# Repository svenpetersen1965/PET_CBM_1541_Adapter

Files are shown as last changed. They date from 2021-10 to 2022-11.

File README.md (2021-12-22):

# PET_CBM_1541_Adapter
This is an adapter for connecting the 1541 (or other IEC floppy disk drives) to the Userport of a CBM8032 etc. It is the reconstruction of a hardware, that fits to an old EPROM, that was found in a CBM8032. Most likely, it works with other BASIC 4.0 CBM/PET computers.

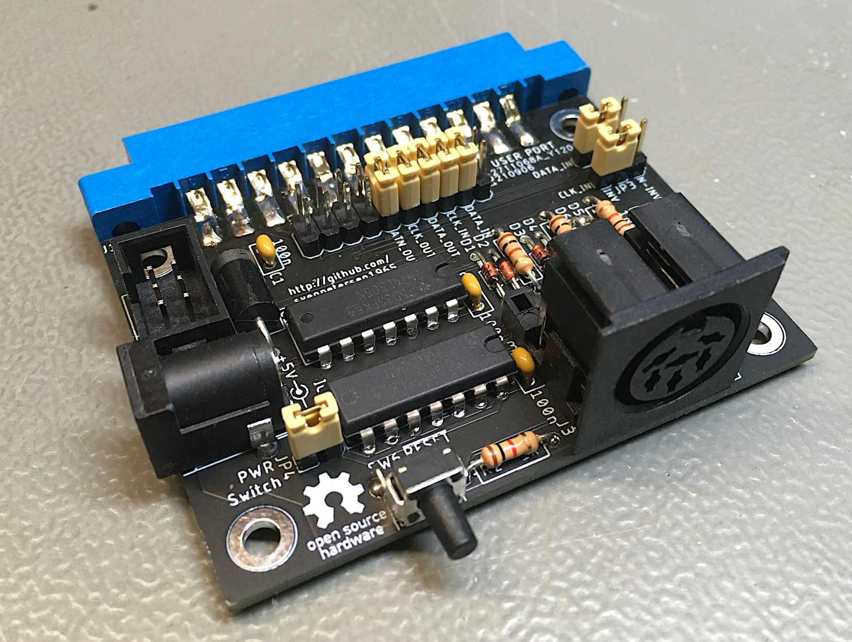
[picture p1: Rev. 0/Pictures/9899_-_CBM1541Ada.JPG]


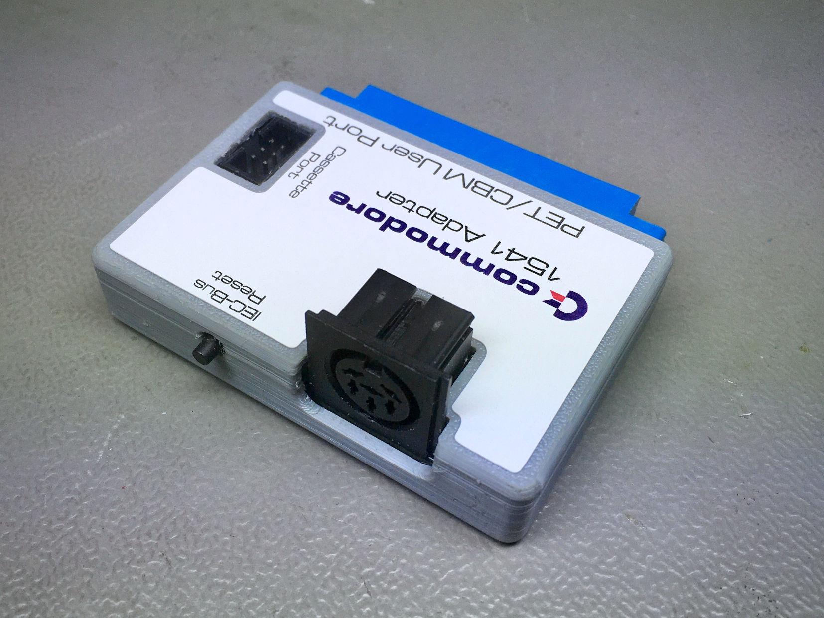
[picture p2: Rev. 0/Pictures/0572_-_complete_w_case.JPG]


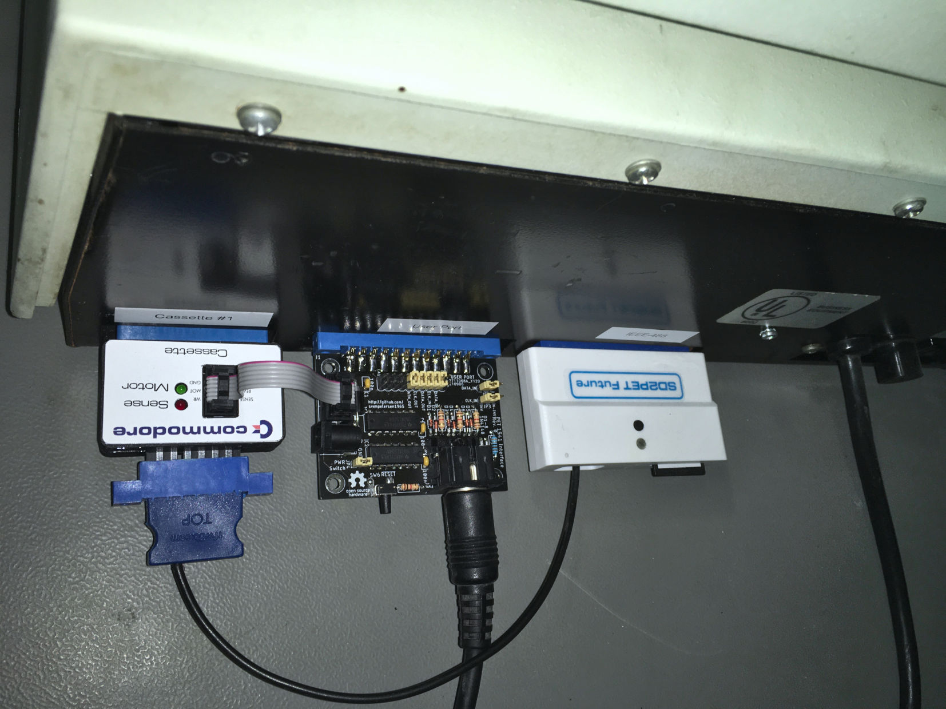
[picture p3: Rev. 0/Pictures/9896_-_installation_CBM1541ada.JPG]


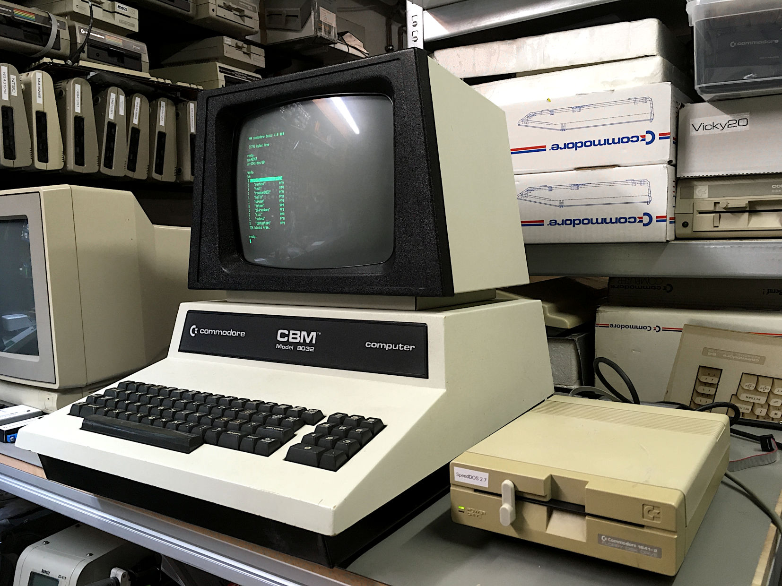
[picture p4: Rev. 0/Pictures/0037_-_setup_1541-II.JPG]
Setup


For communication with the disk drive, a special instruction set is required.

•	each instruction starts with '!'<br> 
•	there are a couple of floppy disk related instructions, that have an alternative representation in the EPROM<br>
•	a !q will deactivate/quite the software<br>
•	a !@ will display the status of the 1541<br>
•	a !@"command" will send a command to the 1541<br>
•	No device number (,8) is required for any of the instructions<br>
•	The instructions are mostly standard BASIC4 instructions and can be short-cut as usually

!load"progname": 	       loads a program from 1541 <br>
!save"progname": 	       saves a program to 1541 <br>
!verify"progname":	       verifies a program <br>
!catalog: 	               displays the driectory of the floppy disk in the 1541 <br>
!open#SA,"file name": 	   it requires a # and after that it is a secondary address* <br>
!print#,"text": 	         prints a texts, also a secondary address after #* <br>
!get#: 	   * <br>
!close#SA: 	               closes a file, also a secondary address after #* <br>
!input#SA: *<br>  
!cmd: *<br>

The items marked with * require some further investigation. See the test documentation.

The software resides in a 2532 EPROM in UD11 and is started with SYS40960.

Find more in the project documentation and <a href="http://tech.guitarsite.de/cbm_1541_ada.html">my website</a> 

Mike Naberezny  did some further inverstigation of the EPROM binary/disassembly and has found out some interesting details. Check out his <a href="https://github.com/mnaberez/vc1541dos">github repository</a>.

# Fixes
The CB2 was improperly labled as CA2. This is fixed in the Gerbers v0a. This had no effect on the function of the circuit.

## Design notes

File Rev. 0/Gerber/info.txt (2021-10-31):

      
       Board: PET_1541_Ada
       Rev.:  0
  
       Files:
       ======
  
       All Gerber files are generated in extended gerber format (RS274X)
       *.TOP        : Film top copper
       *.BOT        :  -"- bottom copper
       *.STC        :  -"- top soldermask 
       *.STS        :  -"- bottom soldermask
       *.PLC        :  -"- silk screen top
       *.DK         : Drills plated Through (Excellon)
       *.NDK        : Drills not plated Through (Excellon)
       *.OUT        : Board outline

       Board Size:
       ===========
       Length     :   68.0 mm
       Width      :   49.0 mm
       Thickness  :   1.6 mm
       Material   :   FR 4
       Copper     :   35 um
       Surface    :   HASL
       
       Remarks:
       ========
       Width >= 8mil
       Distance >= 6mil
       Drill >= 0.35mm

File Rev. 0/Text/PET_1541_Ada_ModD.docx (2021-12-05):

Commodore PET/CBM 1541 Adapter Rev. 0

Module Description

# Introduction

This is a reconstruction of an unknown hardware, which fits to the software from an EPROM, that was discovered in a CBM8032. It is an adapter for a 1541 Floppy Disk Drive, which connects to the User Port of CBM computers like the 8032.

The IEC port only allows to connect a floppy disk drive with device number 8 (which does not interfere with a device number 8 on the IEEE-488 bus!). The instructions for accessing the 1541 are not standard instructions (but very similar). Thus, the 1541 cannot replace an IEEE-488 floppy disk drive, when it comes to accessing files (SEQ or SER) or saving a machine language/assembler program from a monitor like the TIM.

It is good for saving and loading programs on/from the 1541, showing the directory (non- destructive) or displaying the disk status.

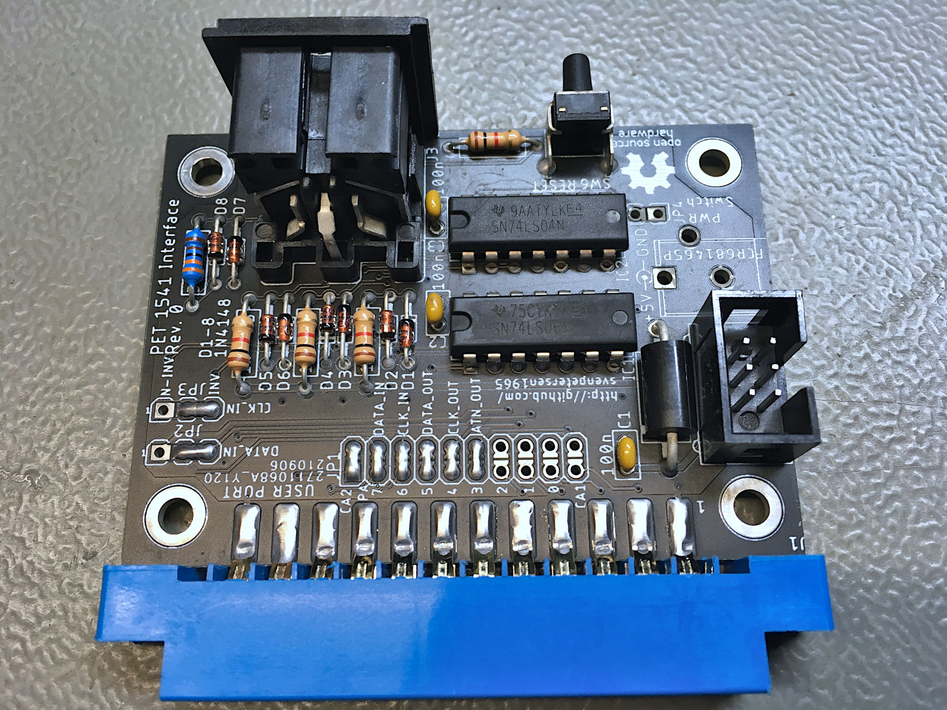
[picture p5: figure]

Figure 1: Standard assembly of the PET/CBM 1541 Adapter with the minimal required components

# Requirements

Since the User Port of the CBM and PETs does not provide a 5V supply voltage, it can be tapped at a cassette port dongle. It is recommended to use the C64 diagnostic harness cassette dongle for this purpose (it can be found here: https://github.com/svenpetersen1965/C64-Diagnostic-Rev.-586220-Harness). Further, the 6 pin ribbon cable of the previously mentioned project is required.

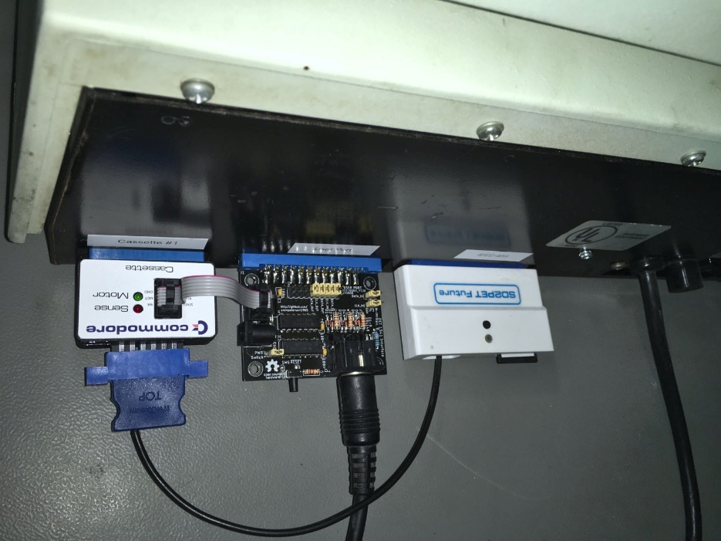
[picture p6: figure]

Figure 2: PET/CBM 1541 adapter with cassette port dongle (and an SD2PET) with a CBM8032

Also, the VC-1541-DOS/80 EPROM is required to be installed in the EPROM socket UD11.

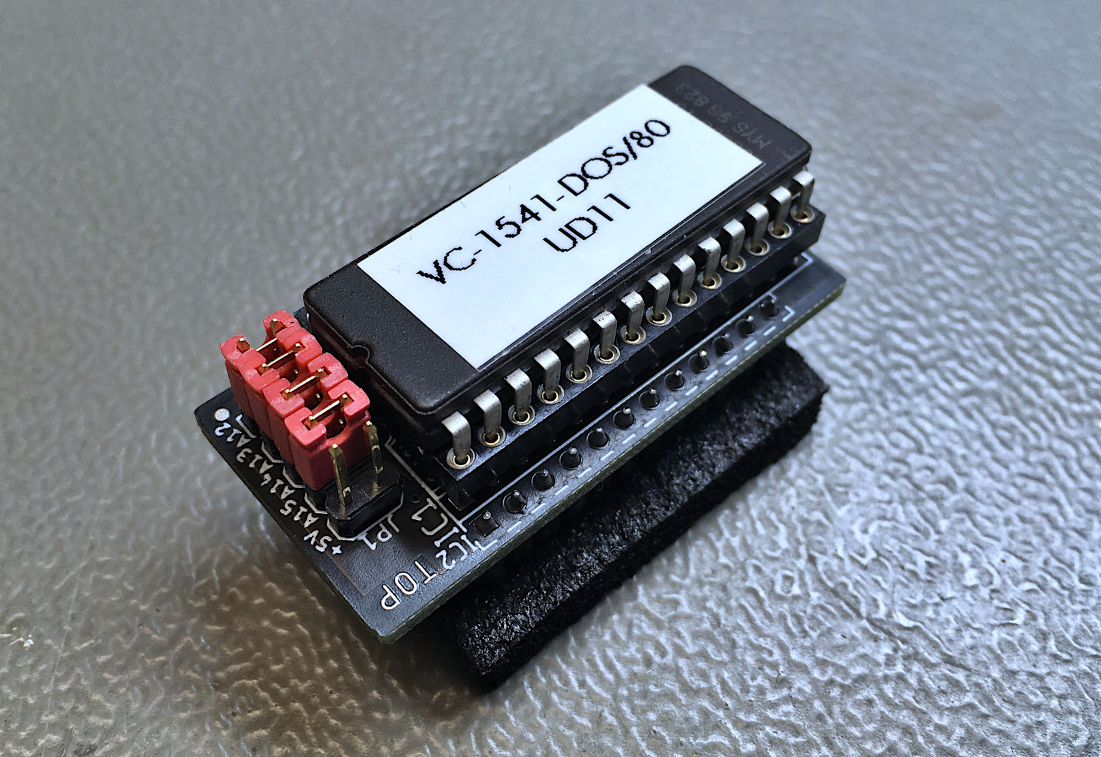
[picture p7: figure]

Figure 3: The Driver Software EPROM.

Originally, the driver software was burned in a TMS2532 4kB EPROM, which directly fits in the socket UD11 on the CBM mainboard. Since those are hard to get and not programmable with many EPROMmers, like the TL866, very likely, an adapter is required like shown in Figure 3.

# Instruction Set

The instruction set was derived from analyzing the binary of the driver software. The software is started with

SYS40960

The software will answer

vc-1541-dos/80

ready.

The instructions follow these rules:

- each instruction starts with '!'
- there are a couple of floppy disk related instructions, that have an alternative representation in the EPROM
- a !q will deactivate/quite the software
- a !@ will display the status of the 1541
- a !@"command" will send a command to the 1541
- No device number (,8) is required for any of the instructions
- The instructions are mostly standard BASIC4 instructions and can be short-cut as usually

Instruction | Format | Note
load | !load"progname" | loads a program from 1541
save | !save"progname" | saves a program to 1541
verify | !verify"progname" | verifies a program
catalog | !catalog | displays the driectory of the floppy disk in the 1541
open | !open#SA,"file name" | it requires a # and after that it is a secondary address*
print# | !print#,"text" | prints a texts, also a secondary address after #*
get# | * | *
close | !close#SA | closes a file, also a secondary address after #*
input# | !input#SA...* | *
cmd | !cmd...* | *

The items marked with * require some further investigation. See the test documentation.

The commands, which are usually sent to the 1541 via secondary address 15, can be sent with the !@ command.

Command | Function
!@"s:file name" | Scratch the file <file name>
!@"n0:disk name,xx,yy" | Format disk
!@"i" | Initialize disk
!@"v" | Validate disk
!@ | Displays the disk status
[…] | […]

# Dimensions

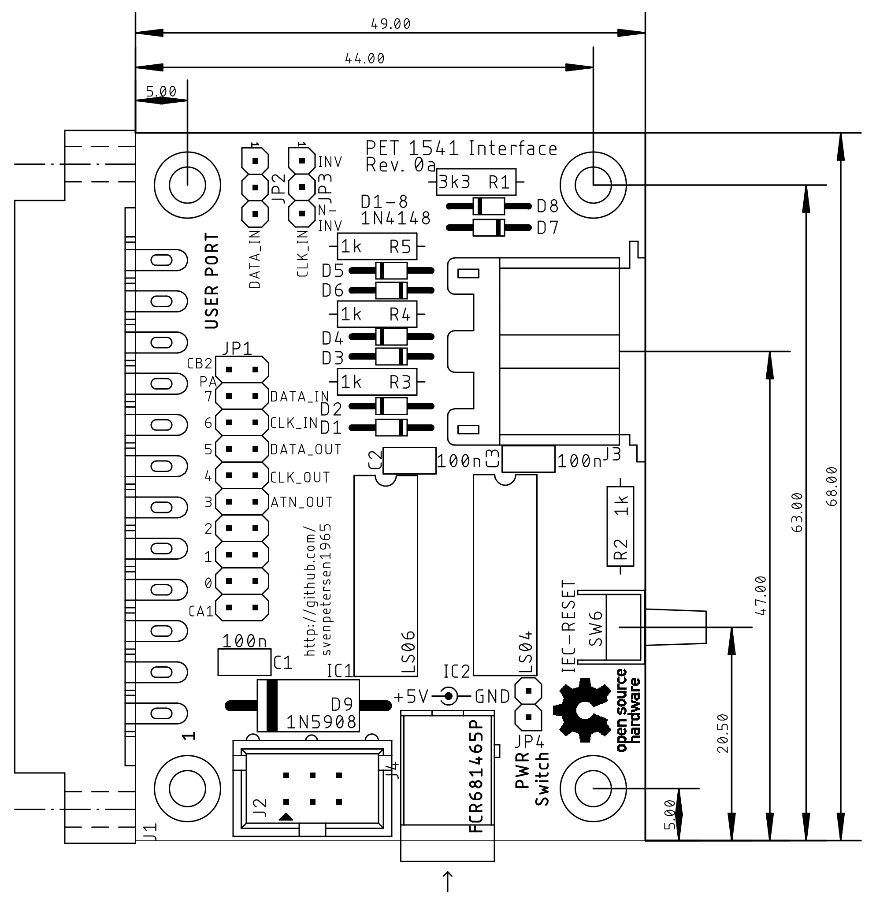
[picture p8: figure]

Figure 4: PCB Dimensions

# RESET Switch – SW6

The RESET Switch is a bus reset for the 1541 only. It does not reset the computer. It is a standard 90° TACT-switch.

# Connectors

## Cassette Port Dongle

J2 – 2x3 pin header for a ribbon cable connected to the cassette port PCB (project number 114).

Pin | Signal | Pin | Signal
1 | GND | 2 | +5V
3 | n.c. | 4 | n.c.
5 | n.c. | 6 | n.c.

n.c.: not connected

## +5VDC Power

J4 - 5,5mm/2,5mm barrel connector

Pin | Signal
Center | +5VDC
Shaft | GND

This connector is optional and not required, if it is intended to power the interface from the cassette port dongle. To make use of it, JP4 has to be closed, which can be achieved with a jumper, a solder bridge or a (power) switch.

## IEC-Bus (1541)

J3 – Lumberg 010599 06, 6p DIN receptacles

Pin | Signal
1 | n.c.
2 | GND
3 | ATN
4 | CLK
5 | DATA
6 | /RESET

/RESET is a drive reset, not a PET reset.

# Jumpers

The jumpers show the experimental character of the prototype design. They can be fix settings and don’t need to be changed at any time. Thus, it is recommended to close them with a solder bridge as shown in Figure 1.

## JP1 - User Port Connections

Signal | Pin | Pin | Signal | Setting
CB2 | 1 | 2 | n.c. | Don’t care
PA7 | 3 | 4 | DATA_IN* | close
PA6 | 5 | 6 | CLK_IN* | close
PA5 | 7 | 8 | DATA_OUT* | close
PA4 | 9 | 10 | CLK_OUT* | close
PA3 | 11 | 12 | ATN_OUT* | close
PA2 | 13 | 14 | n.c. | Don’t care
PA1 | 15 | 16 | n.c. | Don’t care
PA0 | 17 | 18 | n.c. | Don’t care
CA1 | 19 | 20 | n.c. | Don’t care

## JP2, JP3 – Input Inversion

Jumper | Pin 1 | Pin 2 | Pin 3 | Setting
JP2 | /DATA_IN | DATA_IN* | DATA_IN | Non-inverting (2-3)
JP3 | /CLK_IN | CLK_IN* | CLK_IN | Non-inverting (2-3)

## JP4 – Power Switch

This Jumper can be used to connect a power switch or it can be closed. The +5V from the barrel connector are connected to the interface’s supply voltage with the jumper. The +5V from the cassette port dongle are always connected and do not require to be switched. JP4 is only required in conjunction with J3 (See chapter +5VDC Power).

# Revision History

## Rev. 0

- Fully functional prototype

PET_1541_Ada_ModD.docx 05.12.2021 00:55 Drafted by Sven Petersen Page 2 of 2 Doc.-No.: 186-6-01-00

PET_1541_Ada_ModD.docx 05.12.2021 00:55 Drafted by Sven Petersen Page 1 of 1 Doc.-No.: 000-6-00-00

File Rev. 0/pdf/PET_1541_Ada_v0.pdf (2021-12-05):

# Project Documentation

## Commodore PET/CBM 1541 Adapter

## Project number: 186

## Revision: 0

## Date: 23.10.2021

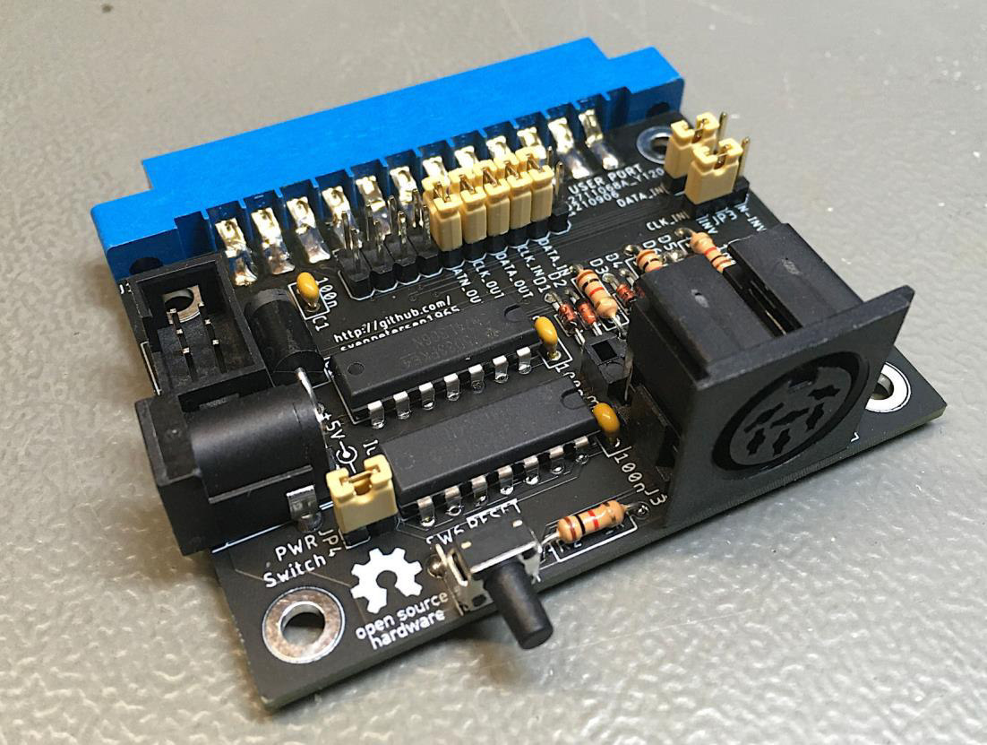
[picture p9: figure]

PET_1541_Ada_ModD.docx | | 05.12.2021 00:55
Drafted by Sven Petersen | Page 1 of 6 | Doc.-No.: 186-6-01-00

## Commodore PET/CBM 1541 Adapter Rev. 0

## Module Description

Table of Content

## Introduction

This is a reconstruction of an unknown hardware, which fits to the software from an EPROM, that was discovered in a CBM8032. It is an adapter for a 1541 Floppy Disk Drive, which connects to the User Port of CBM computers like the 8032.

The IEC port only allows to connect a floppy disk drive with device number 8 (which does not interfere with a device number 8 on the IEEE-488 bus!). The instructions for accessing the 1541 are not standard instructions (but very similar). Thus, the 1541 cannot replace an IEEE-488 floppy disk drive, when it comes to accessing files (SEQ or SER) or saving a machine language/assembler program from a monitor like the TIM.

It is good for saving and loading programs on/from the 1541, showing the directory (non-destructive) or displaying the disk status.

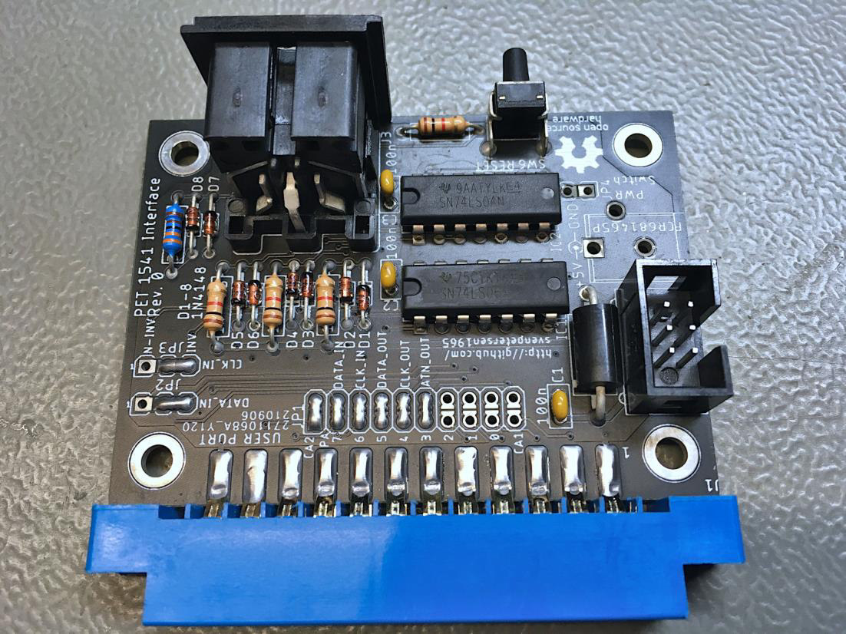
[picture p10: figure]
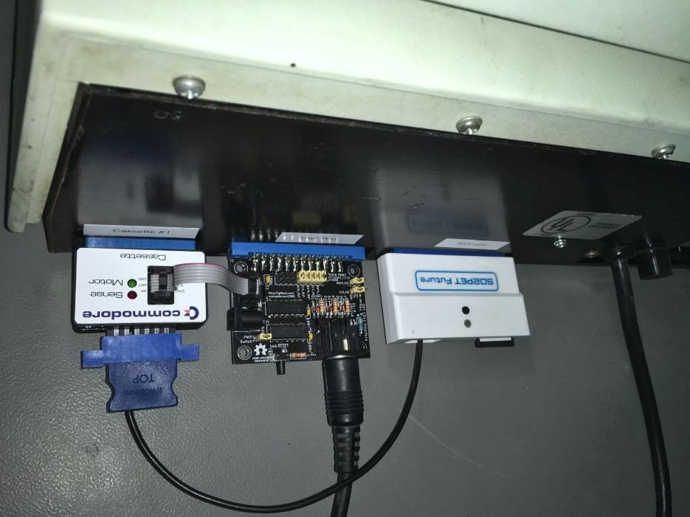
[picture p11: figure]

PET_1541_Ada_ModD.docx | | 05.12.2021 00:55
Drafted by Sven Petersen | Page 2 of 6 | Doc.-No.: 186-6-01-00

Figure 1: Standard assembly of the PET/CBM 1541 Adapter with the minimal required components

## Requirements

Since the User Port of the CBM and PETs does not provide a 5V supply voltage, it can be tapped at a cassette port dongle. It is recommended to use the C64 diagnostic harness cassette dongle for this purpose (it can be found here: https://github.com/svenpetersen1965/C64-Diagnostic-Rev.-586220-Harness). (https://github.com/svenpetersen1965/C64-Diagnostic-Rev.-586220-Harness) Further, the 6 pin ribbon cable of the previously mentioned project is required.

Figure 2: PET/CBM 1541 adapter with cassette port dongle (and an SD2PET) with a CBM8032

Also, the VC-1541-DOS/80 EPROM is required to be installed in the EPROM socket UD11.

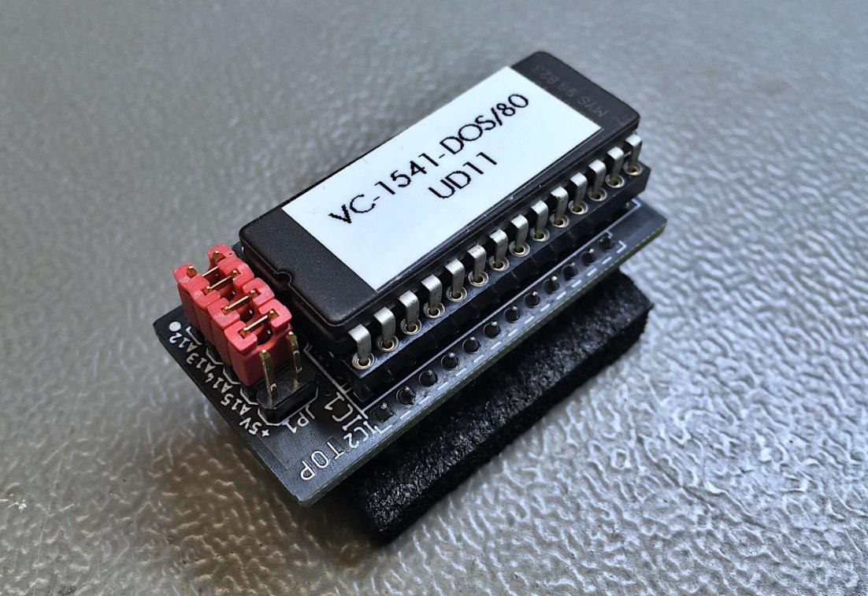
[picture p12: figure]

PET_1541_Ada_ModD.docx | | 05.12.2021 00:55
Drafted by Sven Petersen | Page 3 of 6 | Doc.-No.: 186-6-01-00

Figure 3: The Driver Software EPROM.

Originally, the driver software was burned in a TMS2532 4kB EPROM, which directly fits in the socket UD11 on the CBM mainboard. Since those are hard to get and not programmable with many EPROMmers, like the TL866, very likely, an adapter is required like shown in Figure 3.

## Instruction Set

The instruction set was derived from analyzing the binary of the driver software. The software is started with

SYS40960

The software will answer

vc-1541-dos/80

ready.

The instructions follow these rules:

- each instruction starts with '!'
- there are a couple of floppy disk related instructions, that have an alternative representation in the EPROM
- a !q will deactivate/quite the software
- a !@ will display the status of the 1541
- a !@"command" will send a command to the 1541
- No device number (,8) is required for any of the instructions
- The instructions are mostly standard BASIC4 instructions and can be short-cut as usually

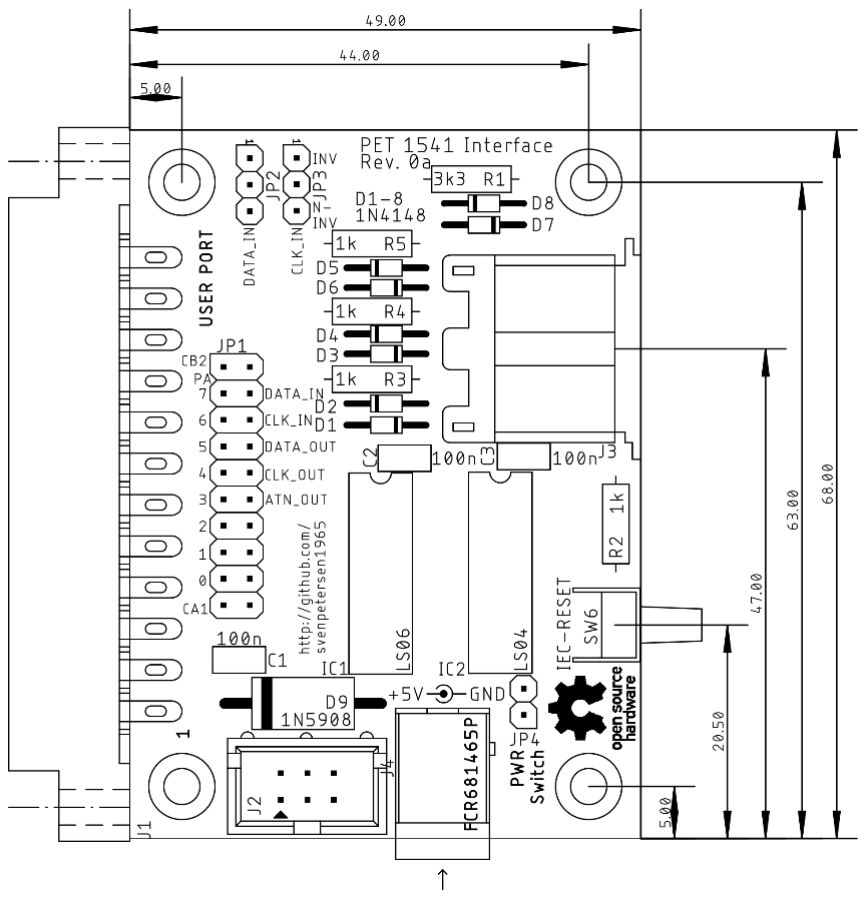
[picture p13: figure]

PET_1541_Ada_ModD.docx | | 05.12.2021 00:55
Drafted by Sven Petersen | Page 4 of 6 | Doc.-No.: 186-6-01-00
Instruction | Format | Note
load | !load"progname" | loads a program from 1541
save | !save"progname" | saves a program to 1541
verify | !verify"progname" | verifies a program
catalog | !catalog | displays the driectory of the floppy disk in the 1541
open | !open#SA,"file name" | it requires a # and after that it is a secondary address*
print# | !print#,"text" | prints a texts, also a secondary address after #*
get# | * | *
close | !close#SA | closes a file, also a secondary address after #*
input# | !input#SA...* | *
cmd | !cmd...* | *
The items marked with * require some further investigation. See the test documentation.

The commands, which are usually sent to the 1541 via secondary address 15, can be sent with the !@ command.

Command | Function
!@"s:file name" | Scratch the file <file name>
!@"n0:disk name,xx,yy" | Format disk
!@"i" | Initialize disk
!@"v" | Validate disk
!@ | Displays the disk status
[…] | […]

## Dimensions

Figure 4: PCB Dimensions

PET_1541_Ada_ModD.docx | | 05.12.2021 00:55
Drafted by Sven Petersen | Page 5 of 6 | Doc.-No.: 186-6-01-00

## RESET Switch – SW6

The RESET Switch is a bus reset for the 1541 only. It does not reset the computer. It is a standard 90° TACT-switch.

## Connectors

### Cassette Port Dongle

J2 – 2x3 pin header for a ribbon cable connected to the cassette port PCB (project number 114).

Pin Signal | Pin Signal
1 | GND | 2 | +5V
3 | n.c. | 4 | n.c.
5 | n.c. | 6 | n.c.
n.c.: not connected

### +5VDC Power

J4 - 5,5mm/2,5mm barrel connector

Pin | Signal
Center | +5VDC
Shaft | GND

This connector is optional and not required, if it is intended to power the interface from the cassette port dongle. To make use of it, JP4 has to be closed, which can be achieved with a jumper, a solder bridge or a (power) switch.

### IEC-Bus (1541)

J3 – Lumberg 010599 06, 6p DIN receptacles

Pin Signal
1 n.c.
2 GND
3 ATN
4 CLK
5 DATA
6 /RESET

/RESET is a drive reset, not a PET reset.

PET_1541_Ada_ModD.docx | | 05.12.2021 00:55
Drafted by Sven Petersen | Page 6 of 6 | Doc.-No.: 186-6-01-00

## Jumpers

The jumpers show the experimental character of the prototype design. They can be fix settings and
don’t need to be changed at any time. Thus, it is recommended to close them with a solder bridge
as shown in Figure 1.

### JP1 - User Port Connections

Signal Pin | Pin Signal Setting
CB2 | 1 | 2 | n.c. | Don’t care
PA7 | 3 | 4 | DATA_IN* | close
PA6 | 5 | 6 | CLK_IN* | close
PA5 | 7 | 8 | DATA_OUT* | close
PA4 | 9 | 10 | CLK_OUT* | close
PA3 | 11 | 12 | ATN_OUT* | close
PA2 | 13 | 14 | n.c. | Don’t care
PA1 | 15 | 16 | n.c. | Don’t care
PA0 | 17 | 18 | n.c. | Don’t care
CA1 | 19 | 20 | n.c. | Don’t care

### JP2, JP3 – Input Inversion

Jumper | Pin 1 | Pin 2 | Pin 3 | Setting
JP2 | /DATA_IN | DATA_IN* | DATA_IN | Non-inverting (2-3)
JP3 | /CLK_IN | CLK_IN* | CLK_IN | Non-inverting (2-3)

### JP4 – Power Switch

This Jumper can be used to connect a power switch or it can be closed. The +5V from the barrel
connector are connected to the interface’s supply voltage with the jumper. The +5V from the
cassette port dongle are always connected and do not require to be switched. JP4 is only required in conjunction with J3 (See chapter +5VDC Power).

## Revision History

### Rev. 0

- Fully functional prototype

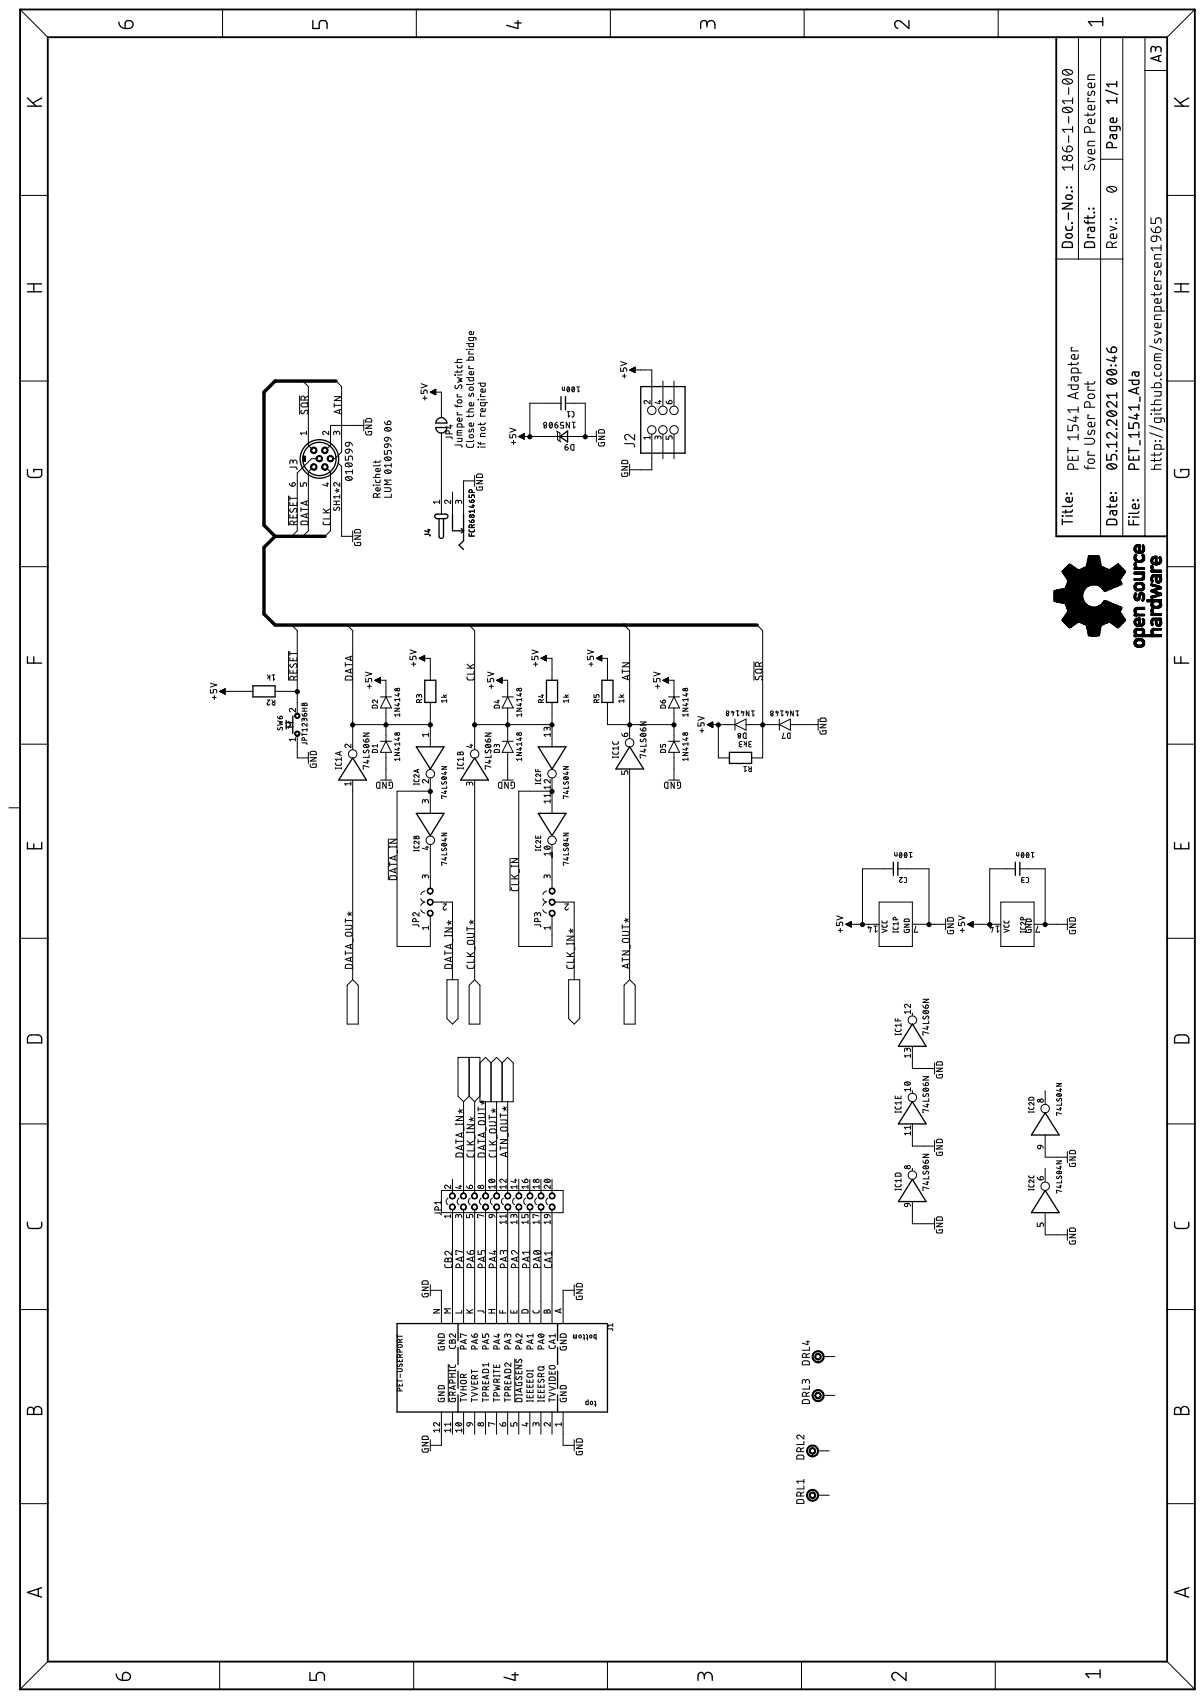
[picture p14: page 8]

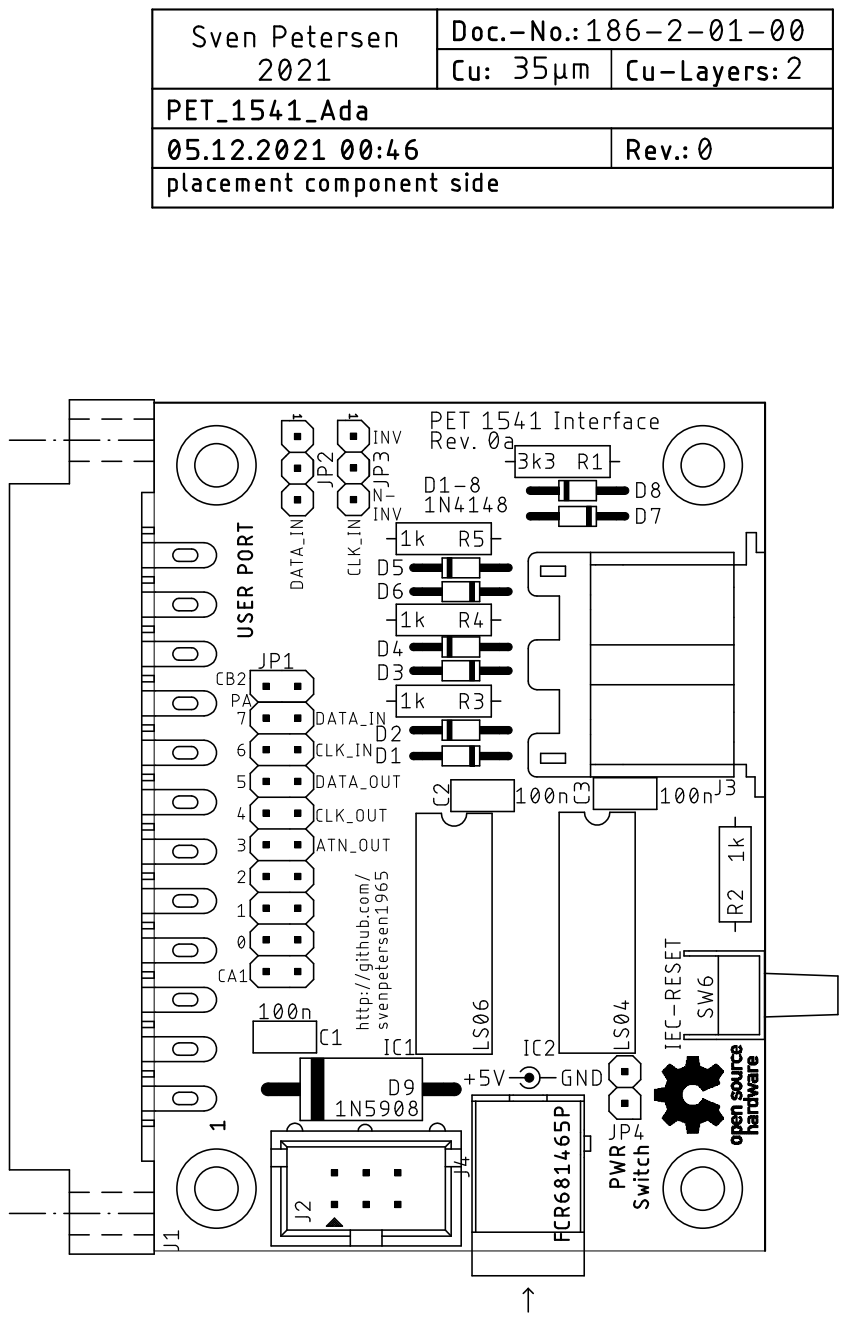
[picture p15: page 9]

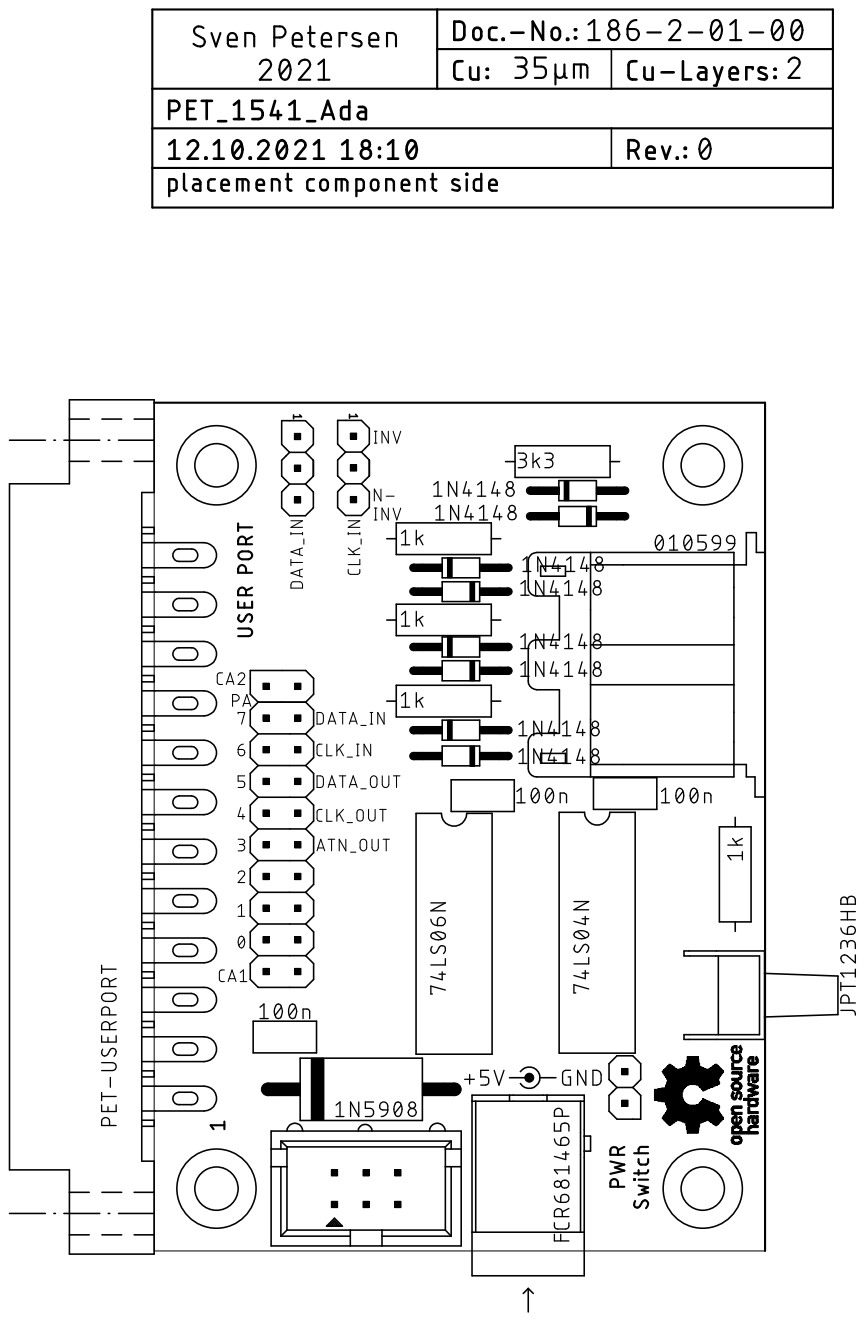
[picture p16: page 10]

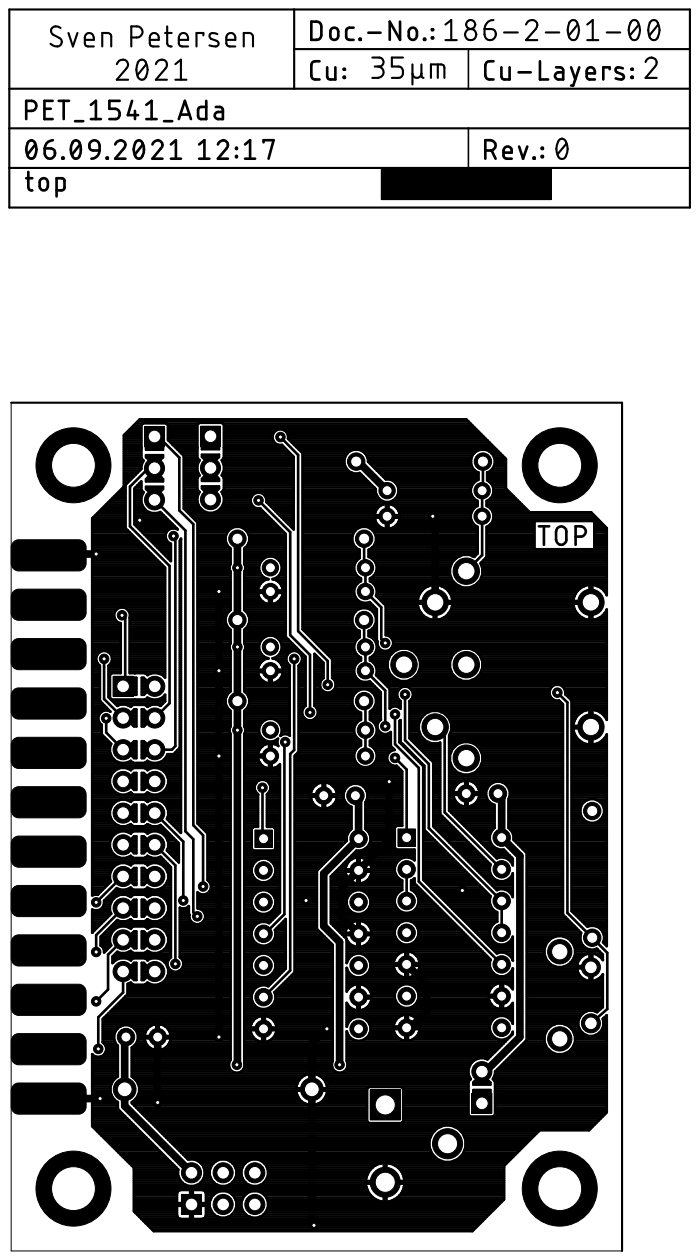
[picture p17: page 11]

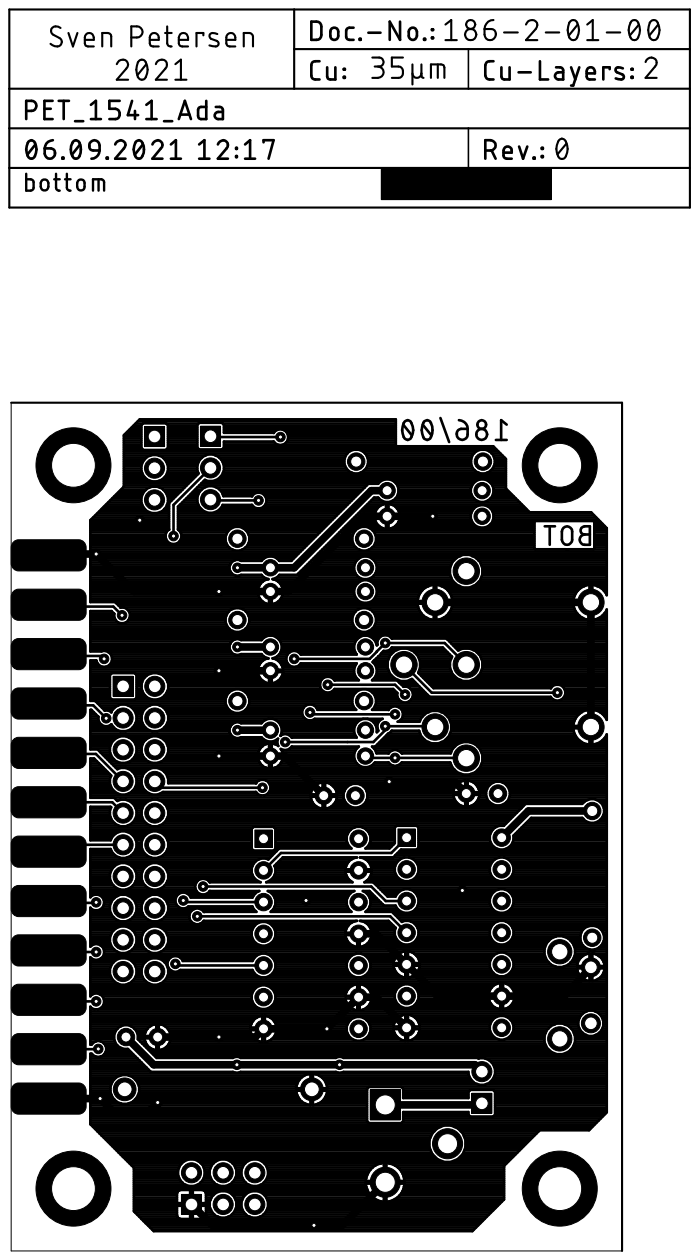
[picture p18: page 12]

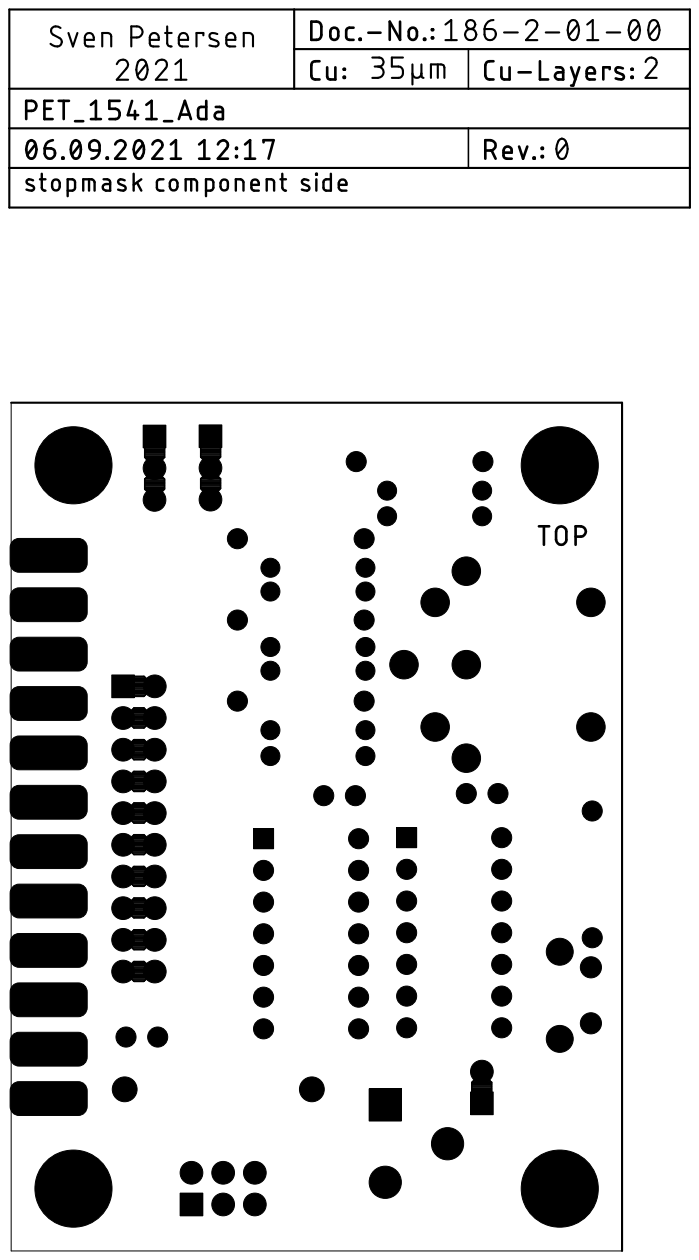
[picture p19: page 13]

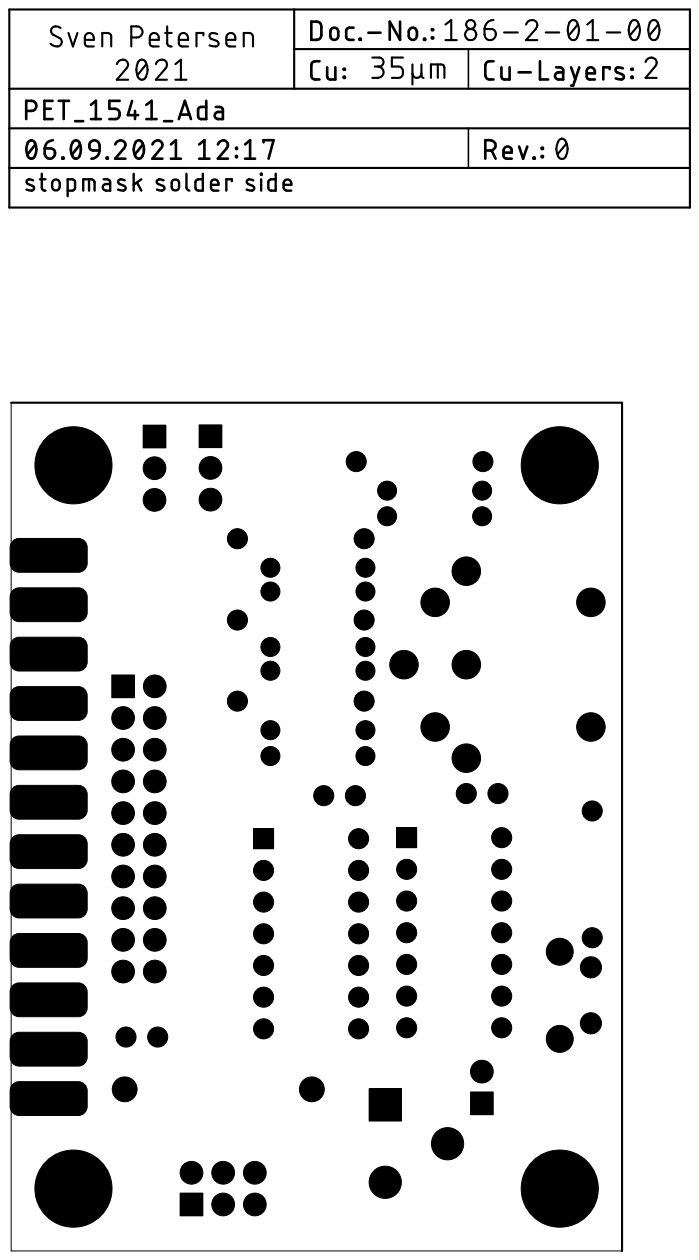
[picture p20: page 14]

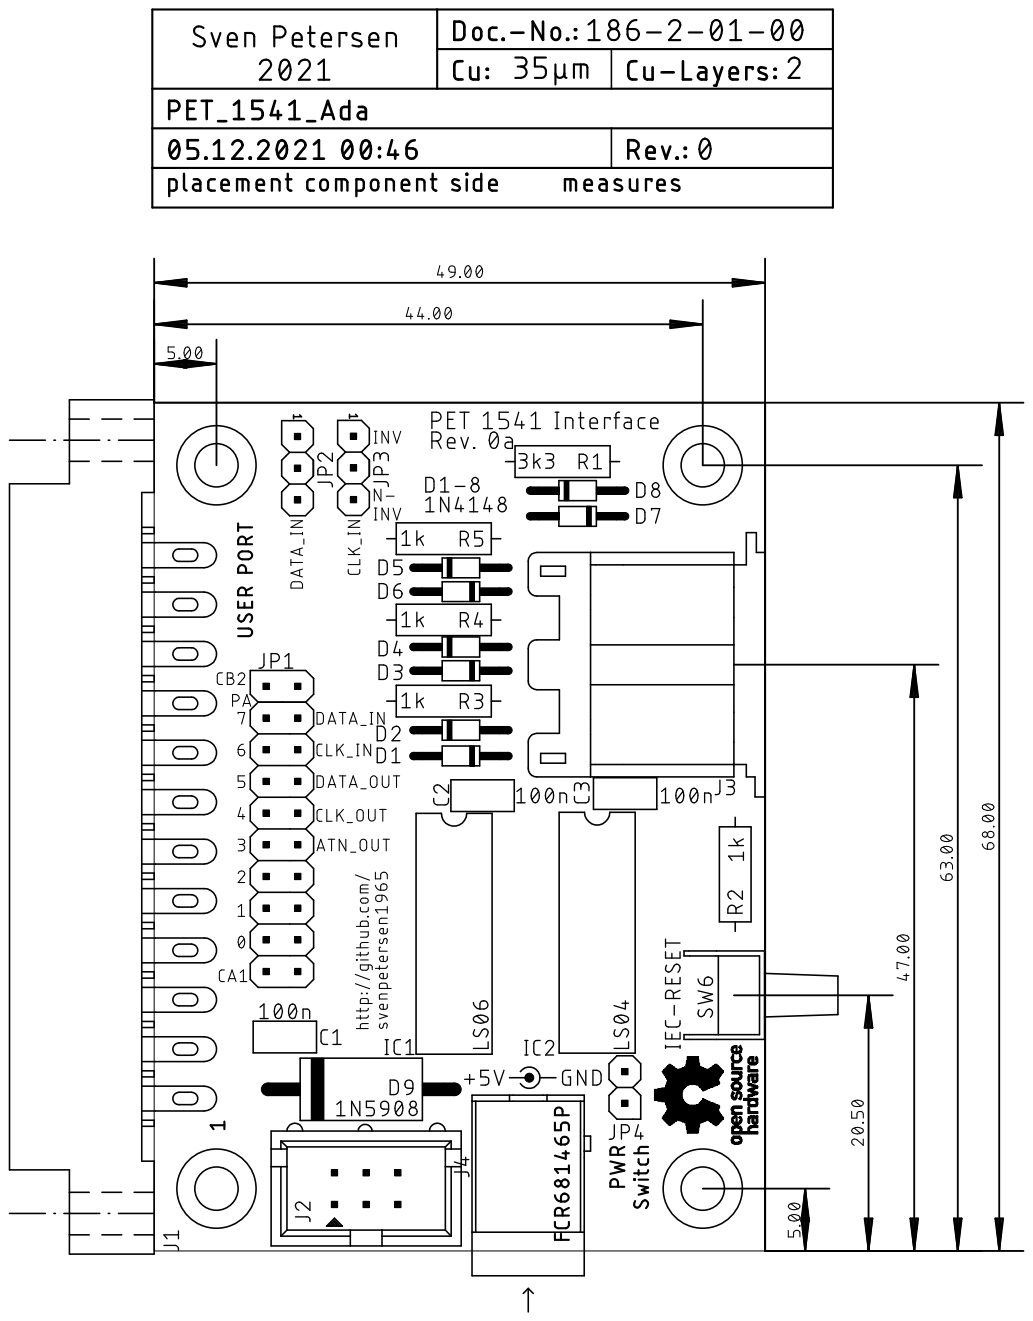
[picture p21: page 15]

PET_1541_Ada_Test_v0.docx | | 31.10.2021 22:39
Drafted by Sven Petersen | Page 1 of 10 | Doc.-No.: 186-6-02-00

## Commodore PET/CBM 1541 Adapter Rev. 0

## Prototype Testing

## Test Setup

- Prototype Rev. 0 installed in the User Port
- CBM8032

### - 2532 EPROM “VC-1541-DOS/80” in UD11

- Cassette Dongle with ribbon cable for power supply
- 1541 and 1541-II disk drives with different floppy disks and serial cable
- SD2IEC with a suitable disk image on SD-card
- Pi1541 with a suitable disk image on SD-card
- 1581 with a suitable disk
- A C64 setup with disk drive to check the files written with

## Test Execution

With each drive, the same tests were executed:

1. Showing the disk status with !@ 2. Formatting the disk with !@”N:CBM8032,00 3. Showing the directory with !catalog 4. Saving a program with !save”<prog name>” 5. Verifying the program with !verify”<prog name>” 6. Loading a program with !load”<prog name> 7. Writing a SEQ file with the program “seqtest” 8. Reading the SEQ file

The sequence of the test steps are not necessarily the same. The program “seqtest” looks like this:

2 print"scratch file"
5 !@"s:test"
7 print"open test for writing 10 !open#1,"test,s,w"
20 fori=1to100
30 !print#1,"This is a test" 40 next
50 !close#1

### General Results

All tests were executed successfully except reading back the sequential file with the CBM8032 on any drive. It turned out, that the file number for !open, !input# etc. is rather a secondary address. An !open#15,”test,s,r” returned a “syntax error” in the status and SA 15 is for sending commands to the disk drive. An !input#2,a$ always returned a “G” in a$ (note: the software was found in an old EPROM and scope of the project is to reconstruct the hardware).

The SEQ file from the CBM8032 was the read with a program on the C64.

50 INPUT"FILE NAME";N$
70 OPEN2,8,2,N$+",S,R"
80 INPUT#2,A$
90 PRINTA$

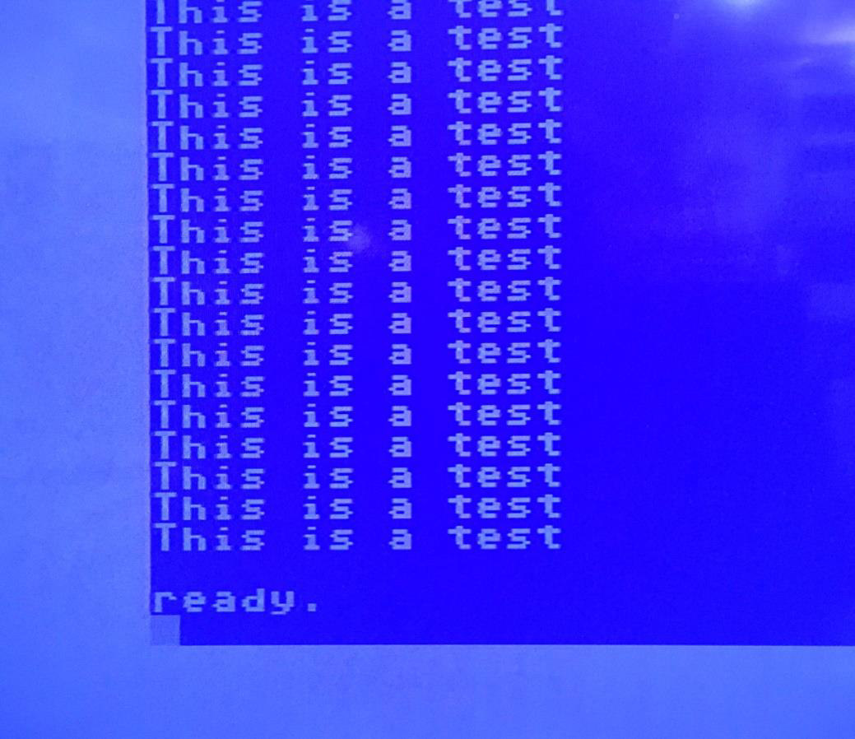
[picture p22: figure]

PET_1541_Ada_Test_v0.docx | | 31.10.2021 22:39
Drafted by Sven Petersen | Page 2 of 10 | Doc.-No.: 186-6-02-00

100 IF ST<>0 THEN120
110 GOTO80
120 CLOSE2

The result looks ok.

Figure 1: The SEQ file read with a C64

Further, the SD2IEC was not capable of the !catalog command. A !load”$” did work, though.

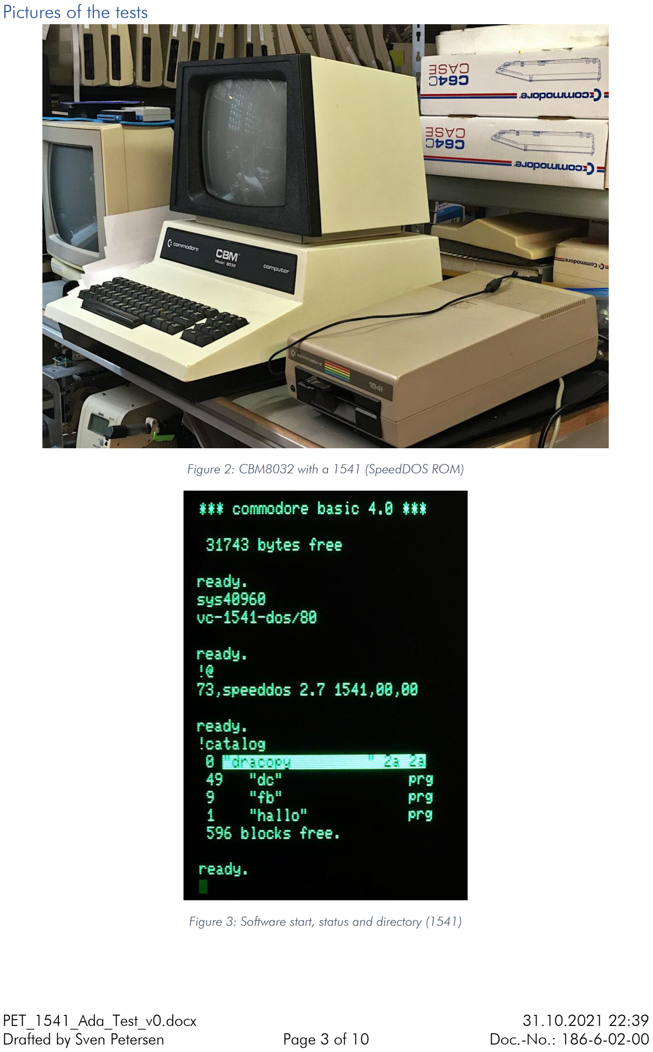
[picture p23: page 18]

PET_1541_Ada_Test_v0.docx | | 31.10.2021 22:39
Drafted by Sven Petersen | Page 3 of 10 | Doc.-No.: 186-6-02-00

### Pictures of the tests

Figure 2: CBM8032 with a 1541 (SpeedDOS ROM)

Figure 3: Software start, status and directory (1541)

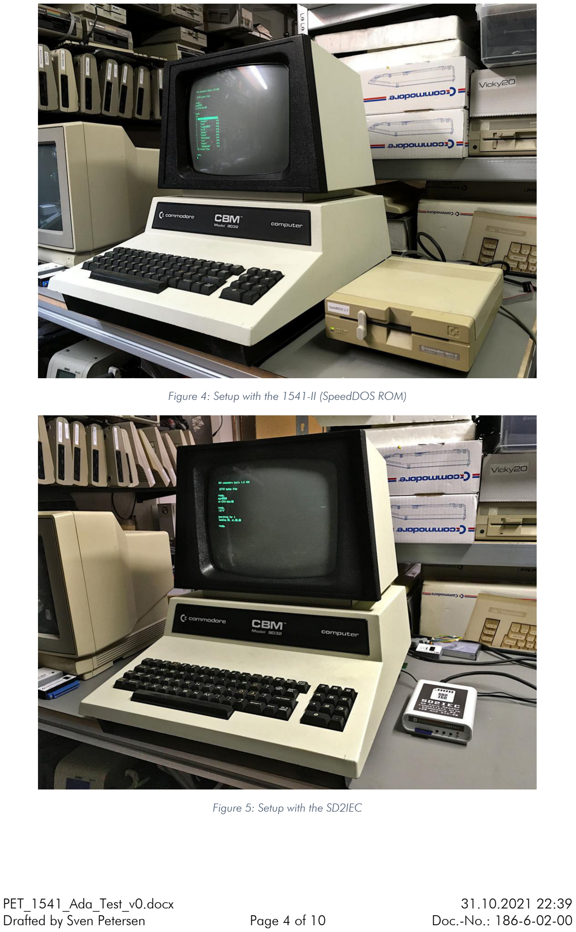
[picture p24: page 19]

PET_1541_Ada_Test_v0.docx | | 31.10.2021 22:39
Drafted by Sven Petersen | Page 4 of 10 | Doc.-No.: 186-6-02-00

Figure 4: Setup with the 1541-II (SpeedDOS ROM)

Figure 5: Setup with the SD2IEC

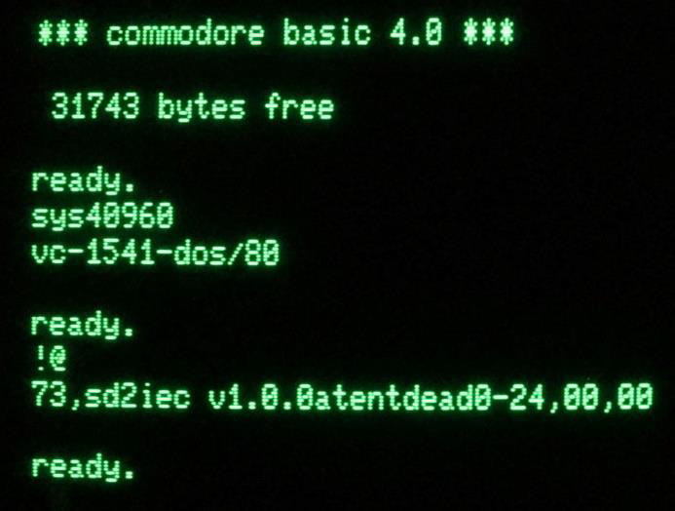
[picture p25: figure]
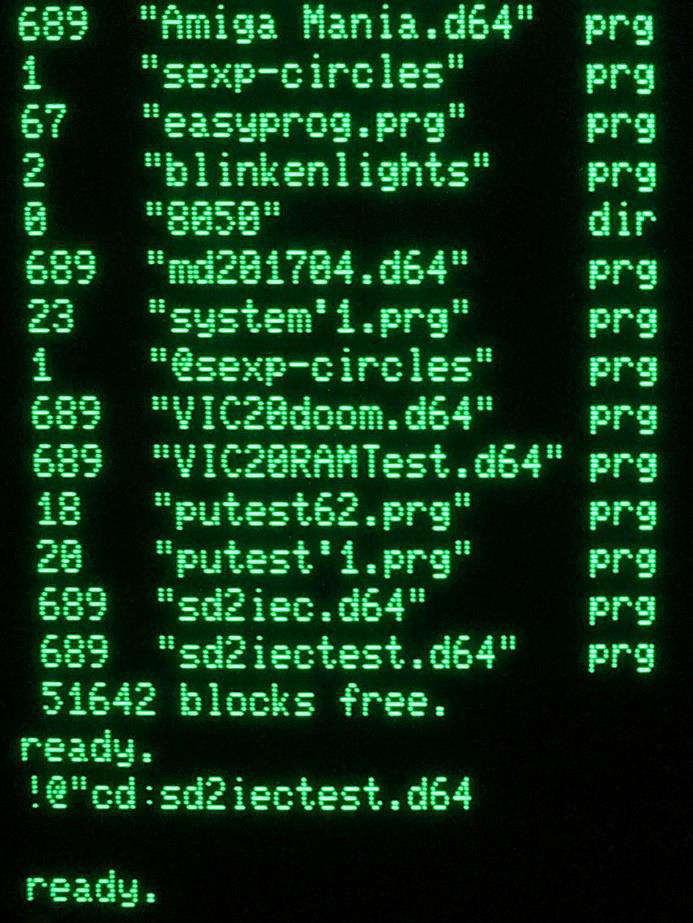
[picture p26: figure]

PET_1541_Ada_Test_v0.docx | | 31.10.2021 22:39
Drafted by Sven Petersen | Page 5 of 10 | Doc.-No.: 186-6-02-00

Figure 6: Software start and status (SD2IEC)

Figure 7: directory and change directory instruction (SD2IEC)

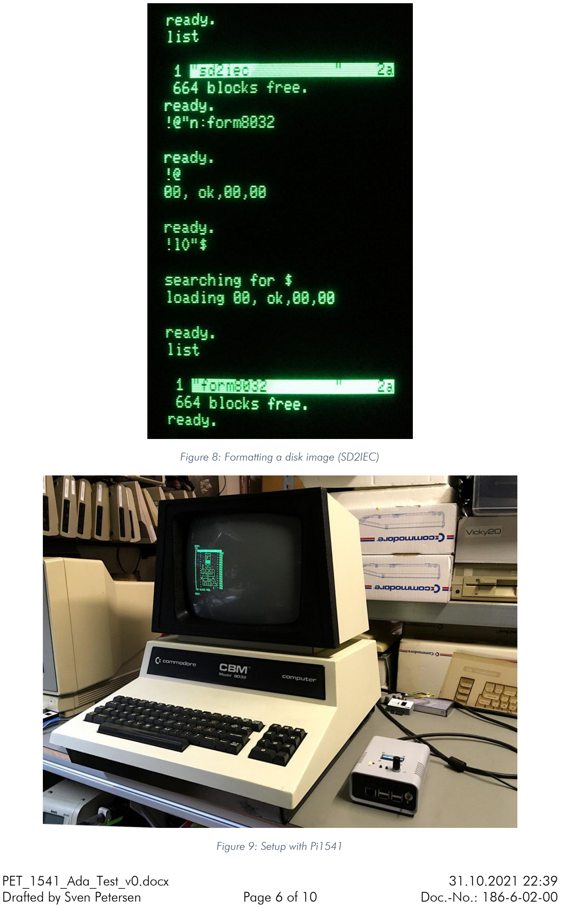
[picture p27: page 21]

PET_1541_Ada_Test_v0.docx | | 31.10.2021 22:39
Drafted by Sven Petersen | Page 6 of 10 | Doc.-No.: 186-6-02-00

Figure 8: Formatting a disk image (SD2IEC)

Figure 9: Setup with Pi1541

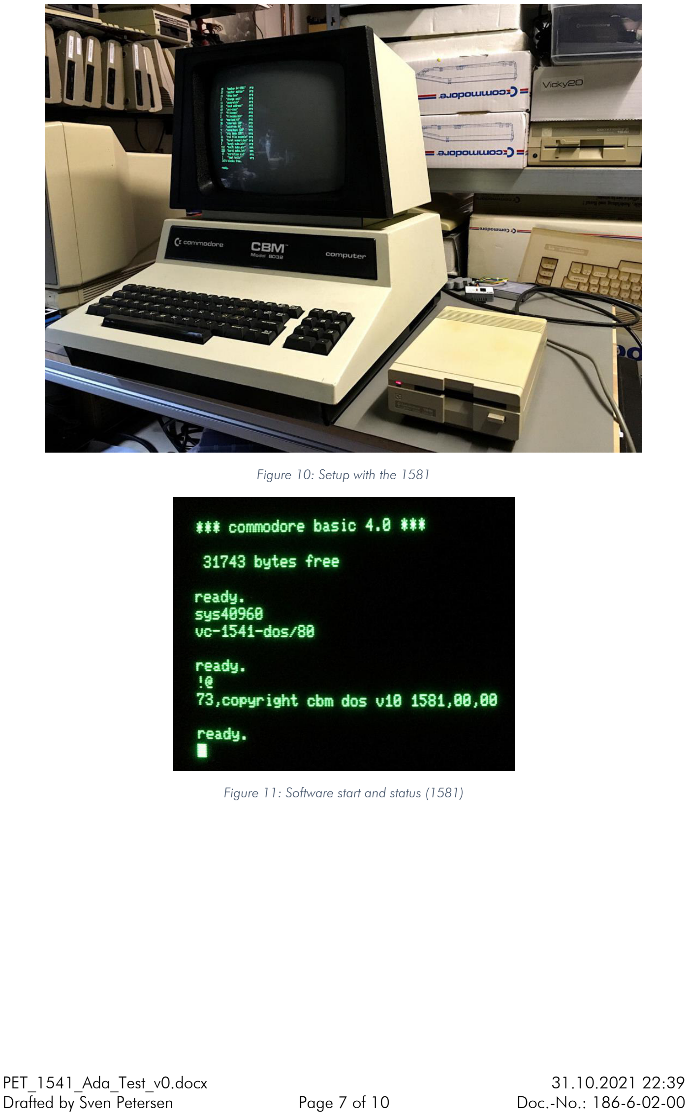
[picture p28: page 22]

PET_1541_Ada_Test_v0.docx | | 31.10.2021 22:39
Drafted by Sven Petersen | Page 7 of 10 | Doc.-No.: 186-6-02-00

Figure 10: Setup with the 1581

Figure 11: Software start and status (1581)


PET_1541_Ada_Test_v0.docx | | 31.10.2021 22:39
Drafted by Sven Petersen | Page 8 of 10 | Doc.-No.: 186-6-02-00

Figure 12: !catalog with the 1581


PET_1541_Ada_Test_v0.docx | | 31.10.2021 22:39
Drafted by Sven Petersen | Page 9 of 10 | Doc.-No.: 186-6-02-00

Figure 13: Test of the 1581 (!save, !verify, !load)

Figure 14: Setup with the Oceanic OC-118N


PET_1541_Ada_Test_v0.docx | | 31.10.2021 22:39
Drafted by Sven Petersen | Page 10 of 10 | Doc.-No.: 186-6-02-00

Figure 15: Status (OC-118N)

## Result

The hardware of the PET/CBM 1541 Adapter is fully functional. The software, that was found in the EPROM seems to work at least mostly. It is not sure, if the !input# and !get# instructions work properly, since the proper instruction syntax might not be figured out, yet.

Pos. Qty Value Footprint Ref.-No. Comment

1 1 186-2-01-00 2 Layer PCB Rev. 0 2 layer, Cu 35µ, HASL, 68.0mm x 49.0mm, 1.6mm FR4

1 2x3 box connector 2X03WV J2 e.g. Reichelt WSL 6G

1 10599 10599 J3 Lumberg, e.g. Reichelt 010599 06, tme.eu: 0105-06

3 100n/50V C-2,5 C1, C2, C3 ceramic capacitor, pitch: 2.5mm

8 1N4148 D1, D2, D3, D4, D5, D6, D7,

D8

standard silicon diode

1 1N5908 CB429 D9 TVS Diode (5V)

4 1k R-10 R2, R3, R4, R5 1/4W, 1%

1 3k3 R-10 R1 1/4W, 1%

1 74LS04N DIL-14 IC2 TI or other

1 74LS06N DIL-14 IC1 TI or other

### 2 COMBI-3P COMBI-3P JP2, JP3 Solder bridge, see Module description

### 1 COMBI_2P COMBI-2P JP4 Solder bridge, see Module description

### 1 COMBI_2X10 COMBI-10X2 JP1 Solder bridge, see Module description

### 1 FCR681465P FCR681465P J4 optional: Cliff, Reichelt: CLIFF FCR681465P, tme.eu:

FCR681465P

### 1 JPT1236HB JTP_1236HB SW6 TACT switch, 90°, Namae Electronics, e.g. Reichelt TASTER

3305B, tme.eu: TACTA-68N-F

1 2x12, 3.96mm pitch USERPORT J1 edge connector, user port

## Commodore PET-1541-Adapter Rev. 0

## Bill of Material Rev. 0.0

PET_1541_Ada_BOM_v0_0.xlsx

Drafted by Sven Petersen Page 1 of 1

23.10.2021 20:20
Doc.No.: 186-5-01-00.0

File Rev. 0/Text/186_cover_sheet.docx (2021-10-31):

Project Documentation

Commodore PET/CBM 1541 Adapter

Project number: 186

Revision: 0

Date: 23.10.2021


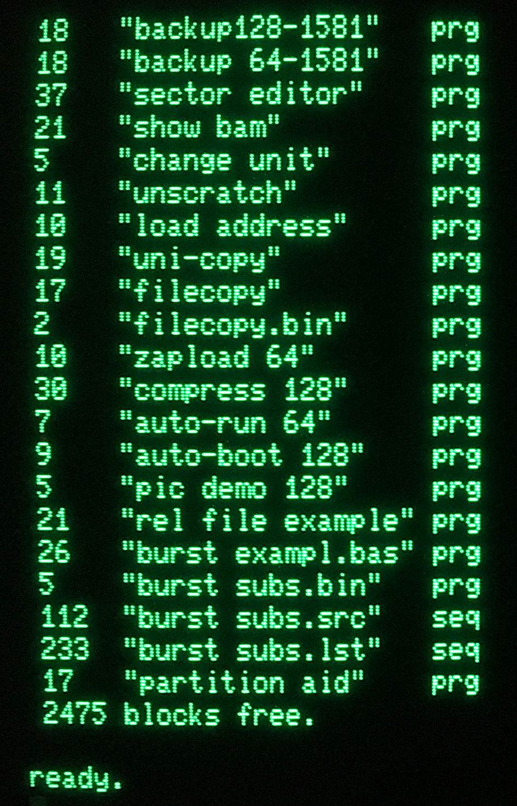
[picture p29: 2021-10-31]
Rev. 0/Pictures/0138_-_catalog_1581.JPG

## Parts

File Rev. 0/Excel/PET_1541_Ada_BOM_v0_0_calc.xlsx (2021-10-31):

Commodore PET-1541-Adapter Rev. 0
BOM value Rev. 0.0
Pos. | Qty | Value | €/ea | € total | Comment
1 | 1 | 186-2-01-00 | 1.00 € | 1.00 € | 2 layer, Cu 35µ, HASL, 68.0mm x 49.0mm, 1.6mm FR4
 | 1 | 2x3 box connector | 0.25 € | 0.25 € | e.g. Reichelt WSL 6G
 | 1 | 10599 | 1.39 € | 1.39 € | Lumberg, e.g. Reichelt 010599 06, tme.eu: 0105-06
 | 3 | 100n/50V | 0.11 € | 0.33 € | ceramic capacitor, pitch: 2.5mm
 | 8 | 1N4148 | 0.02 € | 0.16 € | standard silicon diode
 | 1 | 1N5908 | 0.36 € | 0.36 € | TVS Diode (5V)
 | 4 | 1k | 0.08 € | 0.32 € | 1/4W, 1%
 | 1 | 3k3 | 0.08 € | 0.08 € | 1/4W, 1%
 | 1 | 74LS04N | 0.67 € | 0.67 € | TI or other
 | 1 | 74LS06N | 0.86 € | 0.86 € | TI or other
 | 2 | COMBI-3P | 0.00 € | 0.00 € | Solder bridge, see Module description
 | 1 | COMBI_2P | 0.00 € | 0.00 € | Solder bridge, see Module description
 | 1 | COMBI_2X10 | 0.00 € | 0.00 € | Solder bridge, see Module description
 | 1 | FCR681465P | 1.00 € | 1.00 € | optional: Cliff, Reichelt: CLIFF FCR681465P, tme.eu: FCR681465P
 | 1 | JPT1236HB | 0.18 € | 0.18 € | TACT switch, 90°, Namae Electronics, e.g. Reichelt TASTER 3305B, tme.eu: TACTA-68N-F
 | 1 | 2x12, 3.96mm pitch | 3.00 € | 3.00 € | edge connector, user port
 |  | Total |  | 9.60 €

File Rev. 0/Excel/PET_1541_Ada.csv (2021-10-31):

Qty | Value | Device | Package | Parts | Description
1 |  | 2X03WV | 2X03WV | J2
4 |  | BOHR3,5 | BOHR3,5 | DRL1, DRL2, DRL3, DRL4
1 | 010599 | 010599 | 010599 | J3
3 | 100n | CAP01 | C-2,5 | C1, C2, C3
8 | 1N4148 | 1N41480.3";DO-35/3" | D1, D2, D3, D4, D5, D6, D7, D8
1 | 1N5908 | 1N5908 | CB429 | D9
4 | 1k | RES04 | R-10 | R2, R3, R4, R5
1 | 3k3 | RES04 | R-10 | R1
1 | 74LS04N | 7404DIL | DIL-14 | IC2
1 | 74LS06N | 7406N | DIL-14 | IC1
2 | COMBI-3P | COMBI-3P | COMBI-3P | JP2, JP3
1 | COMBI_2P | COMBI_2P | COMBI-2P | JP4
1 | COMBI_2X10 | COMBI_2X10 | COMBI-10X2 | JP1
1 | FCR681465P | FCR681465P | FCR681465P | J4
1 | JPT1236HB | JPT1236HB | JTP_1236HB | SW6
1 | OPEN_SOURCE_HW | OPEN_SOURCE_HW | OPENHW | U$2
1 | PET-USERPORT | PET-USERPORT | USERPORT | J1

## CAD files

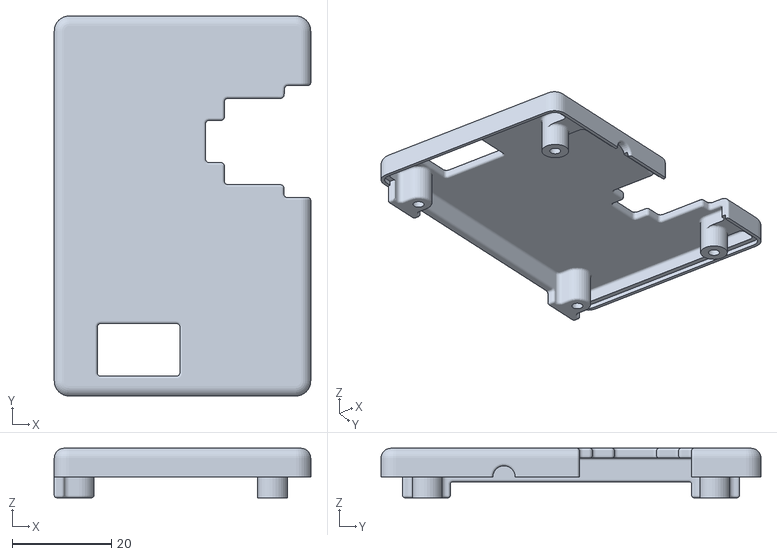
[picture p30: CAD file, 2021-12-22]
3D-print_case/Rev. 0/stl/Top_shell.stl
51.7 x 76.6 x 10.00

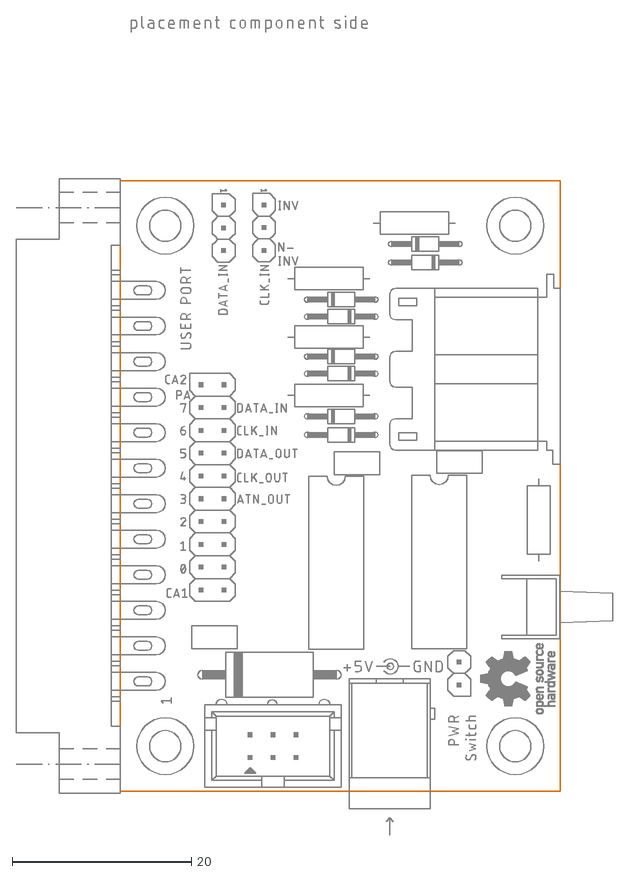
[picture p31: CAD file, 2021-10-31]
Rev. 0/dxf/PET_1541_Ada.dxf
66.5 x 91.3

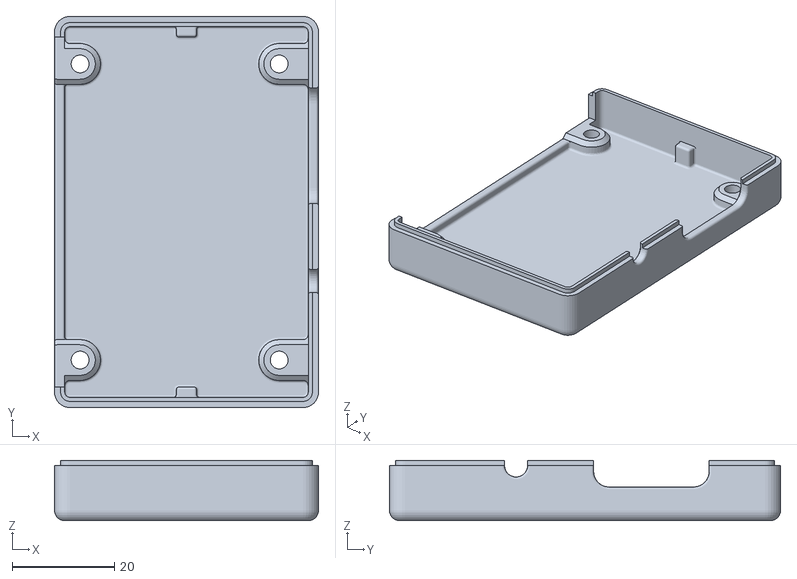
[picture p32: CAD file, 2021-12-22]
3D-print_case/Rev. 0/stl/bottom shell.stl
51.7 x 76.6 x 11.8

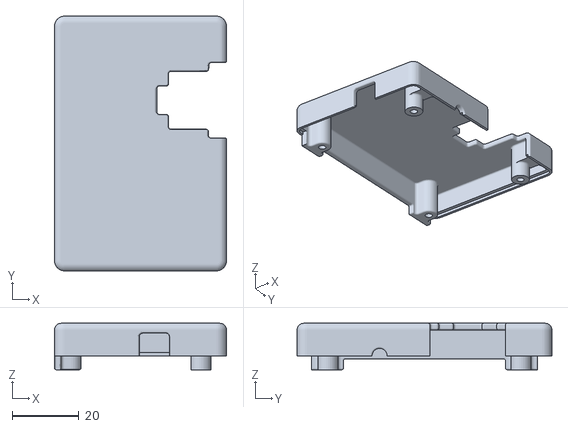
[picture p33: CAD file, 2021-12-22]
3D-print_case/Rev. 0/stl/Top_shell_barrel.stl
51.7 x 76.6 x 14.0

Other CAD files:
3D-print_case/Rev. 0/stl/bottom shell_barrel.stl

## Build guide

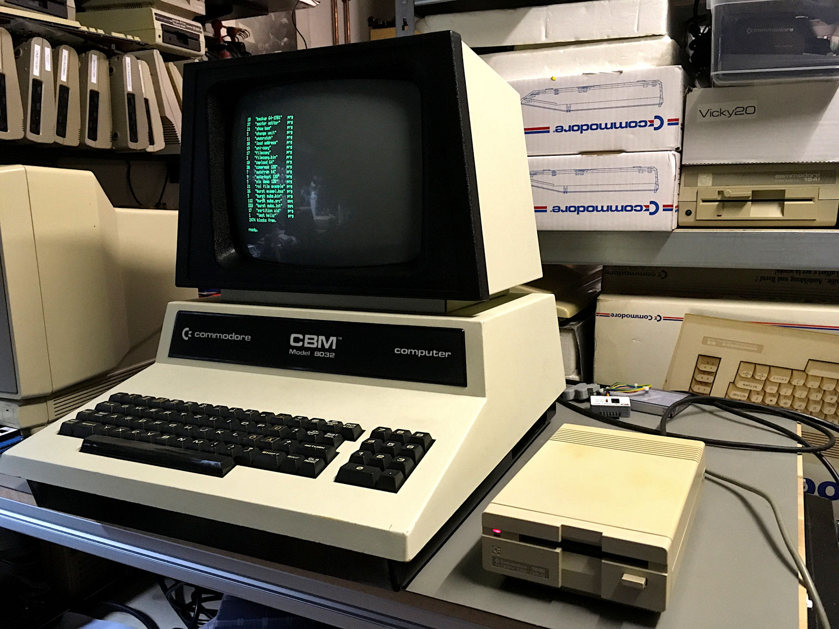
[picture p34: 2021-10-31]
Rev. 0/Pictures/0142_-_setup_1581.JPG

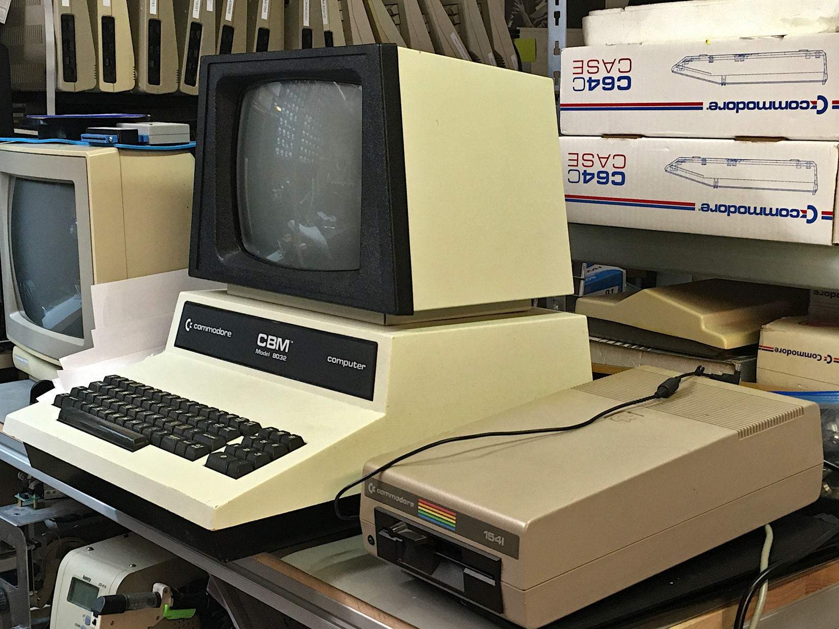
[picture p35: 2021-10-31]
Rev. 0/Pictures/9929_-_setup_1541.JPG

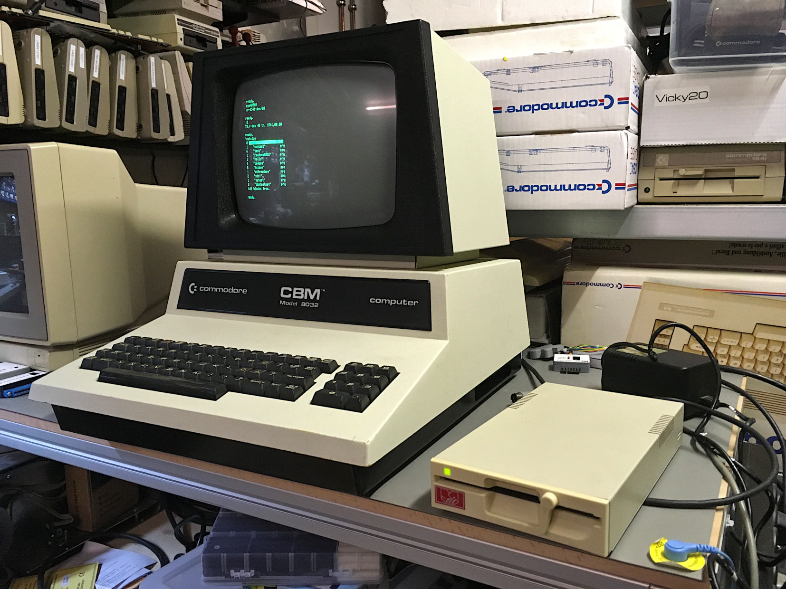
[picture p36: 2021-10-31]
Rev. 0/Pictures/0162_-_setup_OC-118N.JPG

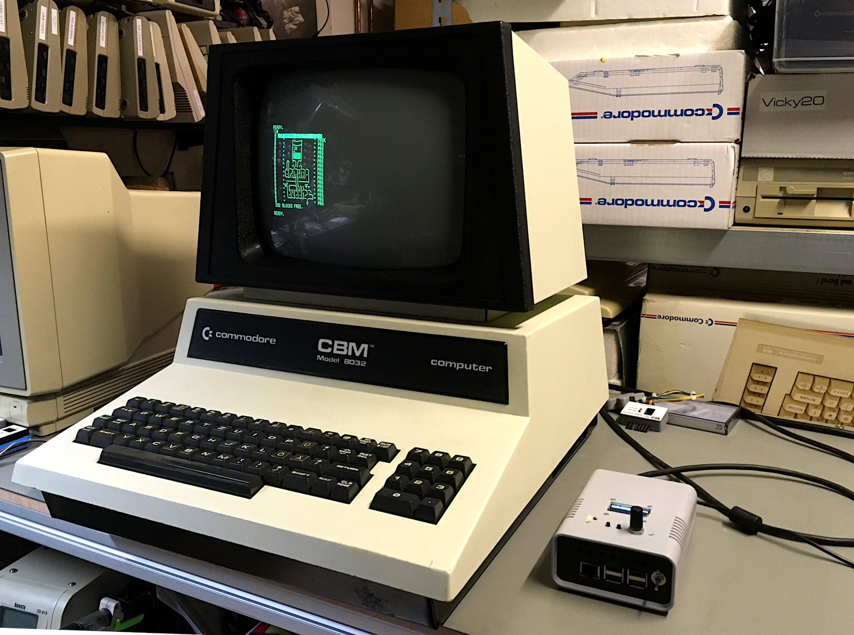
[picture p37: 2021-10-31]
Rev. 0/Pictures/0042_-_setup_Pi1541.JPG

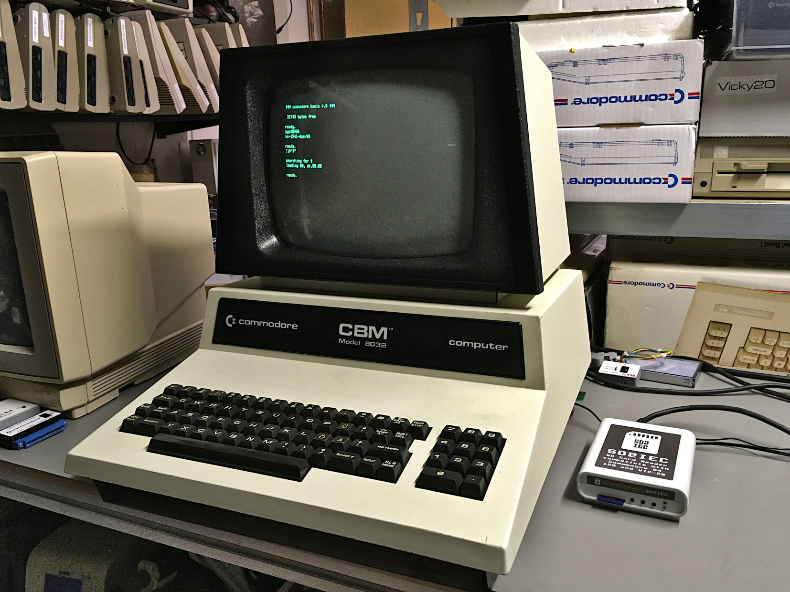
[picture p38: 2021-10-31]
Rev. 0/Pictures/0040_-_setup_SD2IEC.JPG

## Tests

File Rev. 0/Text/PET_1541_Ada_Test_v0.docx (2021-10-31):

Commodore PET/CBM 1541 Adapter Rev. 0

Prototype Testing

# Test Setup

- Prototype Rev. 0 installed in the User Port
- CBM8032
- 2532 EPROM “VC-1541-DOS/80” in UD11
- Cassette Dongle with ribbon cable for power supply
- 1541 and 1541-II disk drives with different floppy disks and serial cable
- SD2IEC with a suitable disk image on SD-card
- Pi1541 with a suitable disk image on SD-card
- 1581 with a suitable disk
- A C64 setup with disk drive to check the files written with

# Test Execution

With each drive, the same tests were executed:

1. Showing the disk status with !@
2. Formatting the disk with !@”N:CBM8032,00
3. Showing the directory with !catalog
4. Saving a program with !save”<prog name>”
5. Verifying the program with !verify”<prog name>”
6. Loading a program with !load”<prog name>
7. Writing a SEQ file with the program “seqtest”
8. Reading the SEQ file

The sequence of the test steps are not necessarily the same. The program “seqtest” looks like this:

2 print"scratch file"
5 !@"s:test"
7 print"open test for writing
10 !open#1,"test,s,w"
20 fori=1to100
30 !print#1,"This is a test"
40 next
50 !close#1

## General Results

All tests were executed successfully except reading back the sequential file with the CBM8032 on any drive. It turned out, that the file number for !open, !input# etc. is rather a secondary address. An !open#15,”test,s,r” returned a “syntax error” in the status and SA 15 is for sending commands to the disk drive. An !input#2,a$ always returned a “G” in a$ (note: the software was found in an old EPROM and scope of the project is to reconstruct the hardware).

The SEQ file from the CBM8032 was the read with a program on the C64.

50 INPUT"FILE NAME";N$
70 OPEN2,8,2,N$+",S,R"
80 INPUT#2,A$
90 PRINTA$
100 IF ST<>0 THEN120
110 GOTO80
120 CLOSE2

The result looks ok.

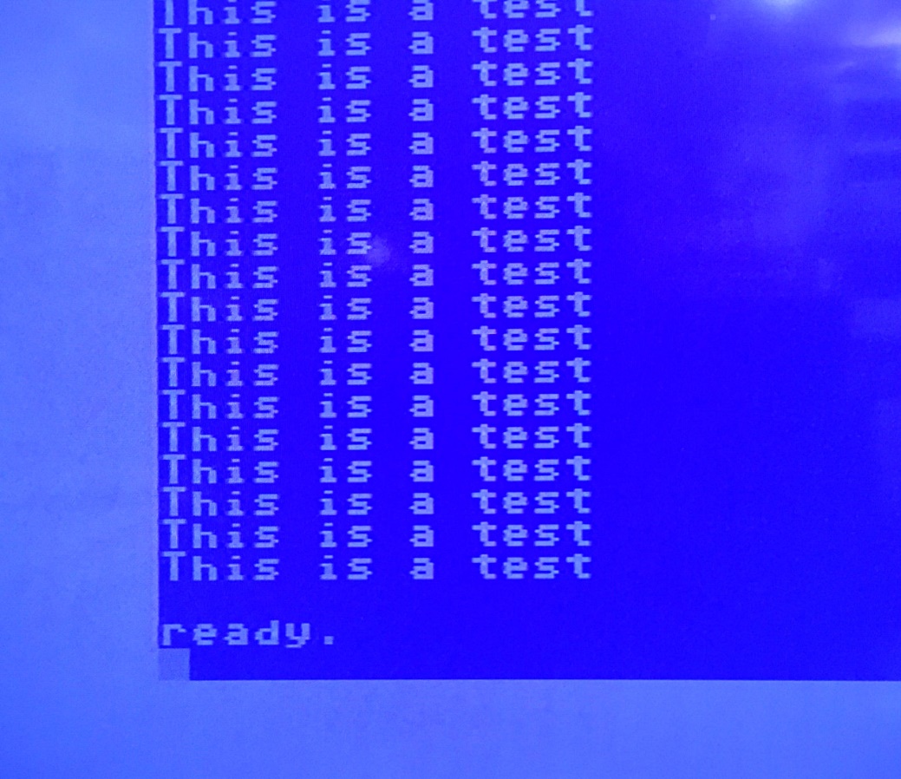
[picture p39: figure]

Figure 1: The SEQ file read with a C64

Further, the SD2IEC was not capable of the !catalog command. A !load”$” did work, though.

## Pictures of the tests


Figure 2: CBM8032 with a 1541 (SpeedDOS ROM)

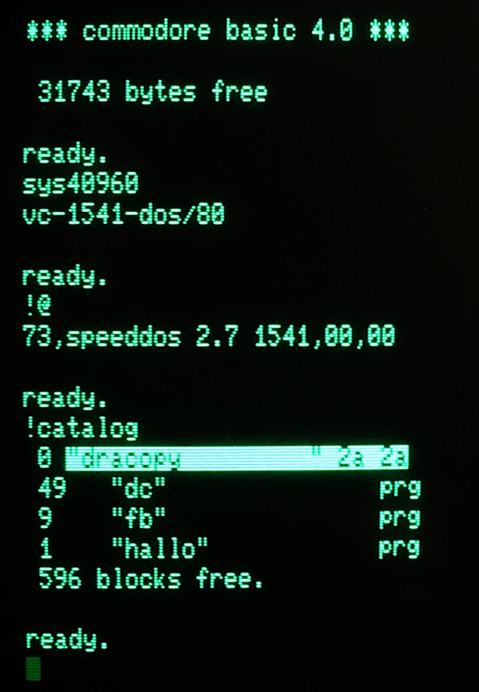
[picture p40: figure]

Figure 3: Software start, status and directory (1541)


Figure 4: Setup with the 1541-II (SpeedDOS ROM)


Figure 5: Setup with the SD2IEC

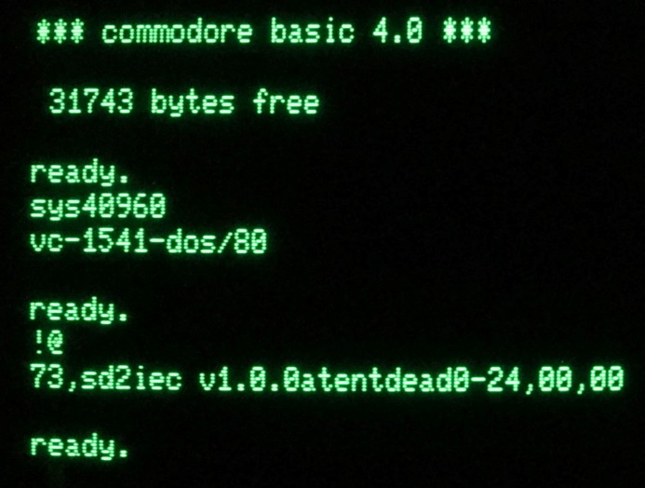
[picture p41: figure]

Figure 6: Software start and status (SD2IEC)

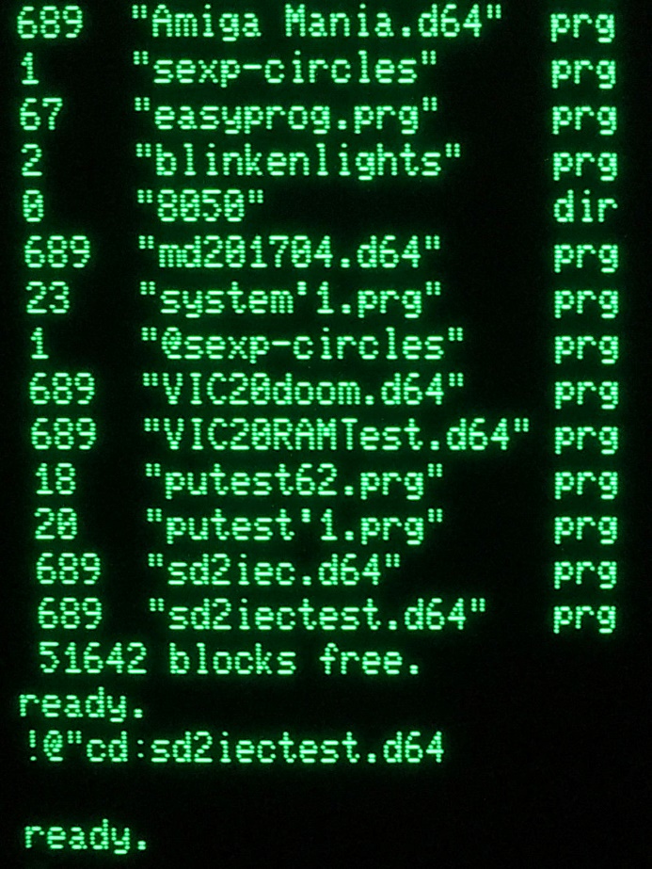
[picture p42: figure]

Figure 7: directory and change directory instruction (SD2IEC)

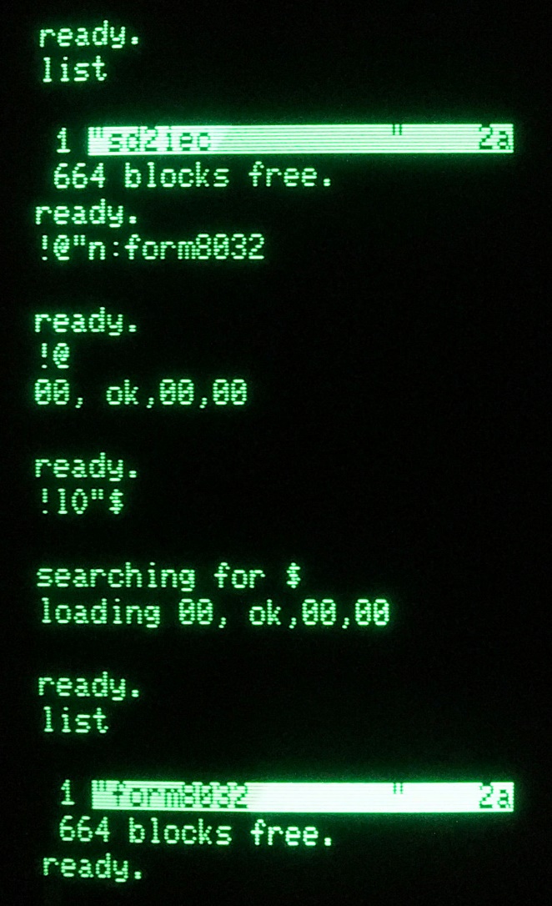
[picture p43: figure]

Figure 8: Formatting a disk image (SD2IEC)


Figure 9: Setup with Pi1541


Figure 10: Setup with the 1581

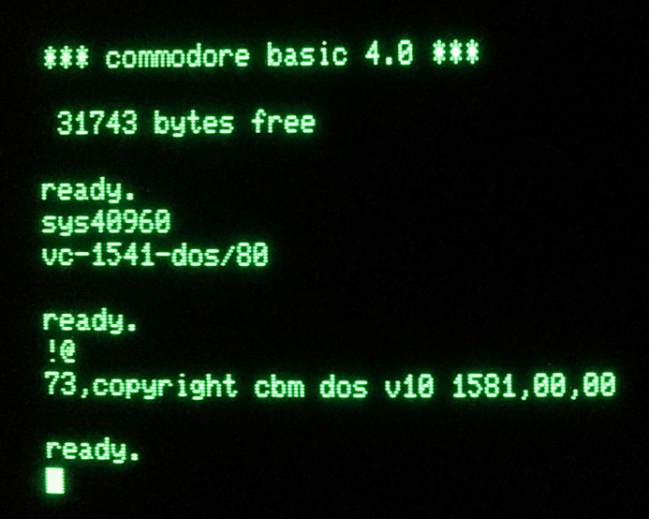
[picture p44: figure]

Figure 11: Software start and status (1581)

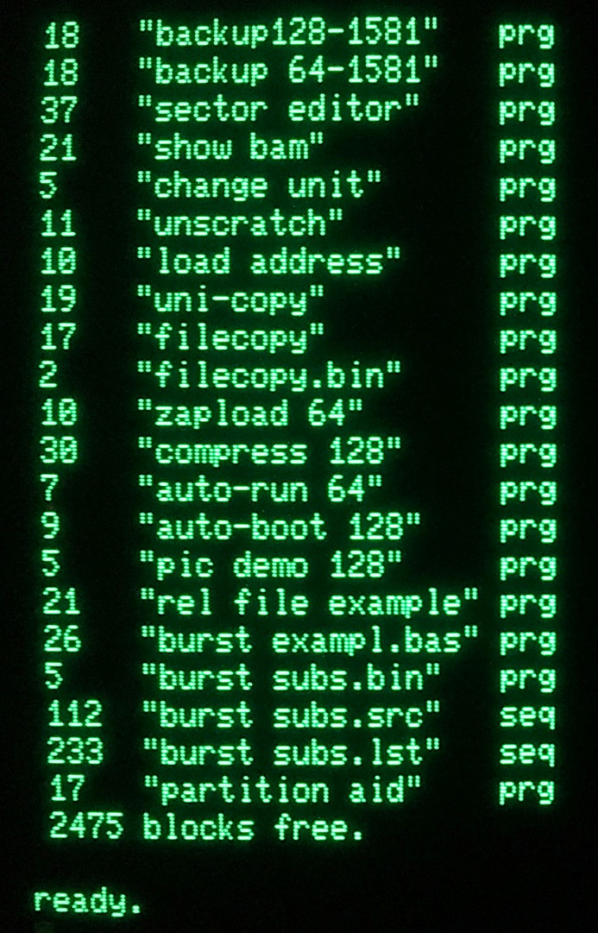
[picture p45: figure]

Figure 12: !catalog with the 1581

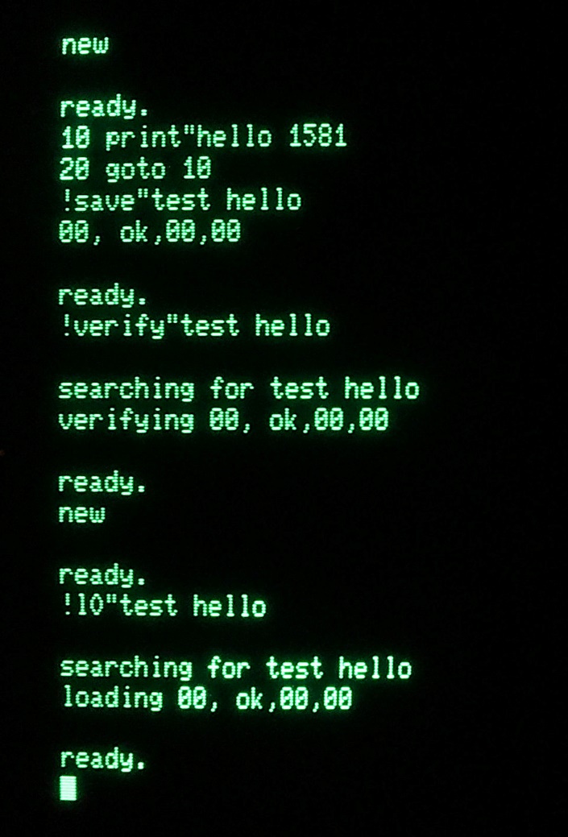
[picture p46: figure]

Figure 13: Test of the 1581 (!save, !verify, !load)


Figure 14: Setup with the Oceanic OC-118N

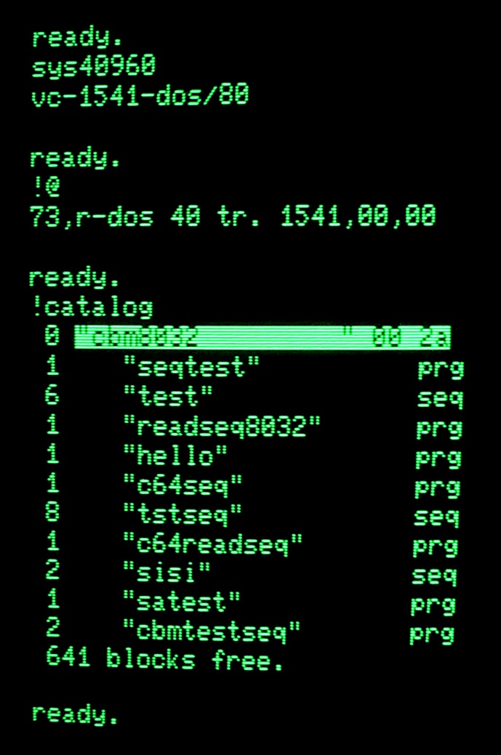
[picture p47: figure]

Figure 15: Status (OC-118N)

# Result

The hardware of the PET/CBM 1541 Adapter is fully functional. The software, that was found in the EPROM seems to work at least mostly. It is not sure, if the !input# and !get# instructions work properly, since the proper instruction syntax might not be figured out, yet.

Dokument1 31.10.2021 18:45 Drafted by Sven Petersen Page 2 of 2 Doc.-No.: 186-6-02-00

Dokument1 31.10.2021 18:45 Drafted by Sven Petersen Page 1 of 1 Doc.-No.: 000-6-00-00

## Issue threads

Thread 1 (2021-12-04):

CB2 Silkscreen Error

mnaberez, 2021-12-04:
There is silkscreen error shown in the photo below.  CB2 is incorrectly marked as CA2.

Note also that in this photo (from page 2 of [the PDF](https://github.com/svenpetersen1965/PET_CBM_1541_Adapter/blob/905ae55b180d998c0385b143dd996a1b26bb2d8f/Rev.%200/pdf/PET_1541_Ada_v0.pdf)), the pads for CB2 have been shorted.  This doesn't do anything.  Ideally, a future version of the PDF would show these pads as open.

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
See also the [schematic](http://zimmers.net/anonftp/pub/cbm/schematics/computers/pet/univ/8032081-03.gif).

svenpetersen1965, 2021-12-05:
Thanks for the hint. I have fixed it (also in the schematics and the docs.
Regards,
Sven

Closed 2021-12-05.

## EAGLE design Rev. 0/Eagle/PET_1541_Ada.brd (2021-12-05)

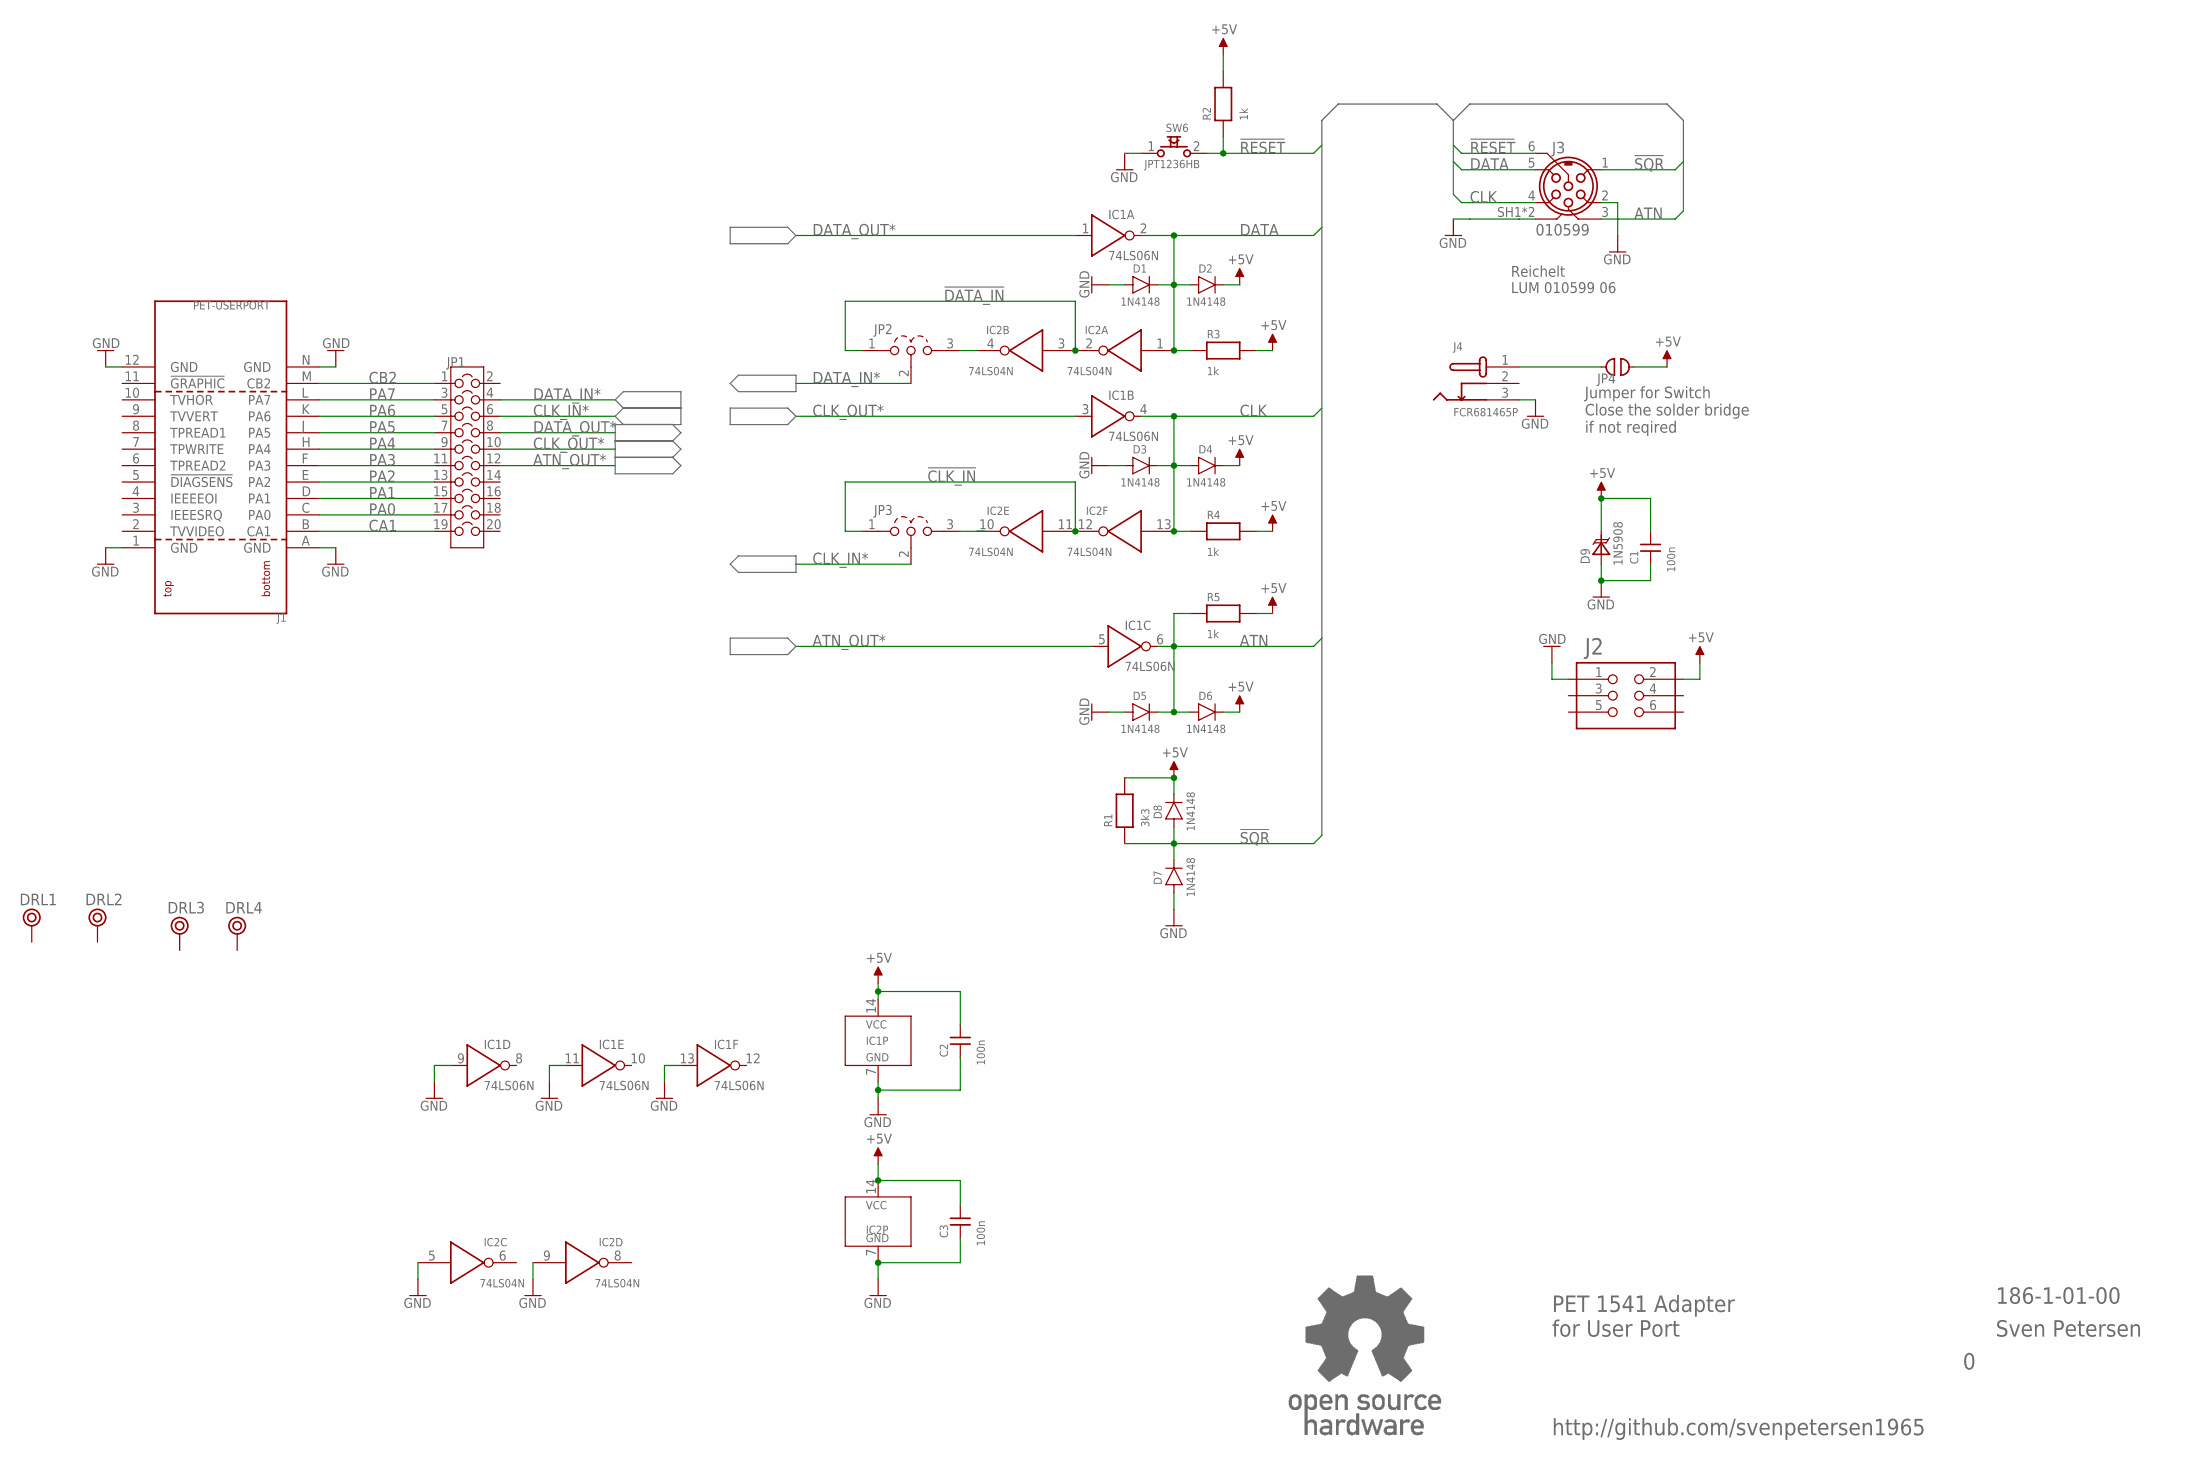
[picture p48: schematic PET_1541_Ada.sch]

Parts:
C1, C2, C3: 100n; C-2,5
D1, D2, D3, D4, D5, D6, D7, D8: 1N4148; DO-35/3
D9: 1N5908; CB429
DRL1, DRL2, DRL3, DRL4: BOHR3,5
IC1: 74LS06N; DIL-14
IC2: 74LS04N; DIL-14
J1: PET-USERPORT; USERPORT
J2: 2X03WV
J3: 010599
J4: FCR681465P
JP1: COMBI_2X10; COMBI-10X2
JP2, JP3: COMBI-3P
JP4: COMBI_2P; COMBI-2P
R1: 3k3; R-10
R2, R3, R4, R5: 1k; R-10
SW6: JPT1236HB; JTP_1236HB
U$2: OPEN_SOURCE_HW; OPENHW

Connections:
!CLK_IN: IC2.11 (I), IC2.12 (O), JP3.1
!DATA_IN: IC2.2 (O), IC2.3 (I), JP2.1
!RESET: J3.6, R2.1, SW6.2
!SQR: D7.K, D8.A, J3.1, R1.1
+5V: C1.2, C2.2, C3.2, D2.K, D4.K, D6.K, D8.K, D9.K, IC1.14 (VCC), IC2.14 (VCC), J2.2, JP4.2, R1.2, R2.2, R3.2, R4.2, R5.2
ATN: D5.K, D6.A, IC1.6 (O), J3.3, R5.1
ATN_OUT*: IC1.5 (I), JP1.12
CA1: J1.B (CA1), JP1.19
CB2: J1.M (CB2), JP1.1
CLK: D3.K, D4.A, IC1.4 (O), IC2.13 (I), J3.4, R4.1
CLK_IN: IC2.10 (O), JP3.3
CLK_IN*: JP1.6, JP3.2
CLK_OUT*: IC1.3 (I), JP1.10
DATA: D1.K, D2.A, IC1.2 (O), IC2.1 (I), J3.5, R3.1
DATA_IN: IC2.4 (O), JP2.3
DATA_IN*: JP1.4, JP2.2
DATA_OUT*: IC1.1 (I), JP1.8
GND: C1.1, C2.1, C3.1, D1.A, D3.A, D5.A, D7.A, D9.A, IC1.7 (GND), IC1.9 (I), IC1.11 (I), IC1.13 (I), IC2.5 (I), IC2.7 (GND), IC2.9 (I), J1.1 (GND), J1.12 (GND), J1.A (GND), J1.N (GND), J2.1, J3.2, J3.SH1 (SH), J3.SH2 (SH), J4.3, SW6.1
unnamed: J4.1, JP4.1
PA0: J1.C (PA0), JP1.17
PA1: J1.D (PA1), JP1.15
PA2: J1.E (PA2), JP1.13
PA3: J1.F (PA3), JP1.11
PA4: J1.H (PA4), JP1.9
PA5: J1.J (PA5), JP1.7
PA6: J1.K (PA6), JP1.5
PA7: J1.L (PA7), JP1.3

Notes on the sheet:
PET 1541 Adapter for User Port
186-1-01-00
Sven Petersen
http://github.com/svenpetersen1965
Reichelt LUM 010599 06
Jumper for Switch Close the solder bridge if not reqired

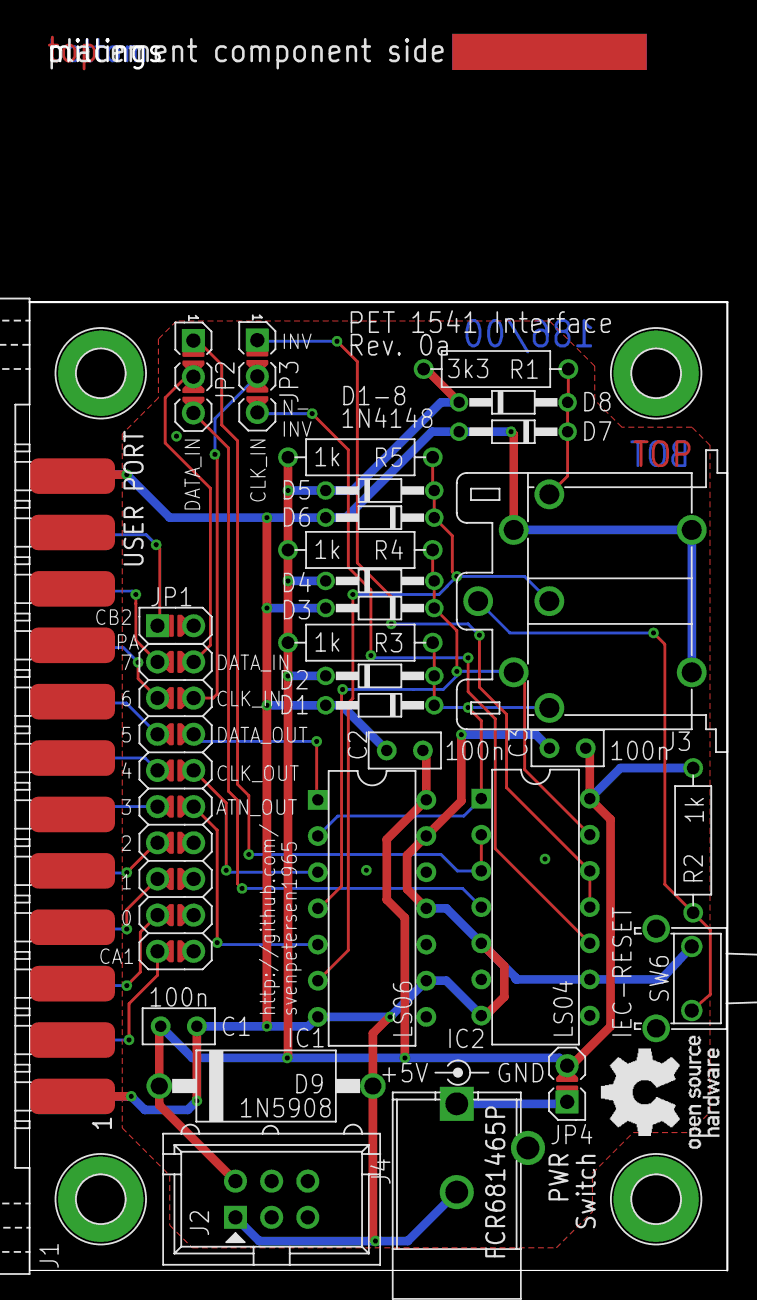
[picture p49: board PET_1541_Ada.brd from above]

Board: 2 copper layers, 49.0 x 68.0 mm, 35 parts (0 on the bottom side), 27 nets.

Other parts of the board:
U$47: 2LAYER
U$48: PCB-TITLE/

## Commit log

2021-10-31 Initial release
    [PET_1541_Ada.brd, PET_1541_Ada.csv, PET_1541_Ada.dxf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]
2021-12-05 CB2 Silk screen fix
    [PET_1541_Ada.brd, PET_1541_Ada.sch]
2021-12-05 Gerber v0 is obsolete
2021-12-22 Picture with case
2021-12-22 3D printed case
    [Top_shell.stl, Top_shell_barrel.stl, bottom shell.stl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]
2022-02-26 Gerbers removed
